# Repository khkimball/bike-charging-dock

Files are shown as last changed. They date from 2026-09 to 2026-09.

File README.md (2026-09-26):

# Bike charging dock

A 3D-printed desk dock for cycling electronics. A multi-port USB charger is
hidden inside, cables run up through the tray to each device, and a hinged lid
closes over them. The shell tapers at 15 degrees on every side and prints in
two colours, a dark foot band and a light body.

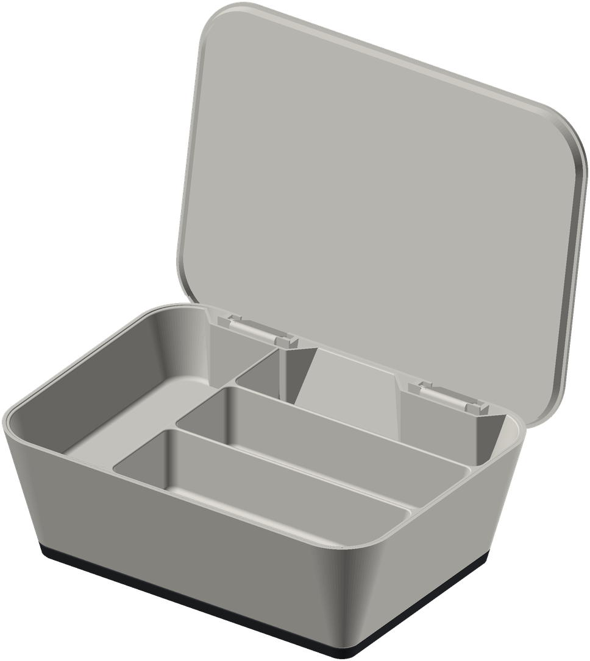
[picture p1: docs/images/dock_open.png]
The dock, open


| Closed | Tray from above | Base from behind |
|---|---|---|
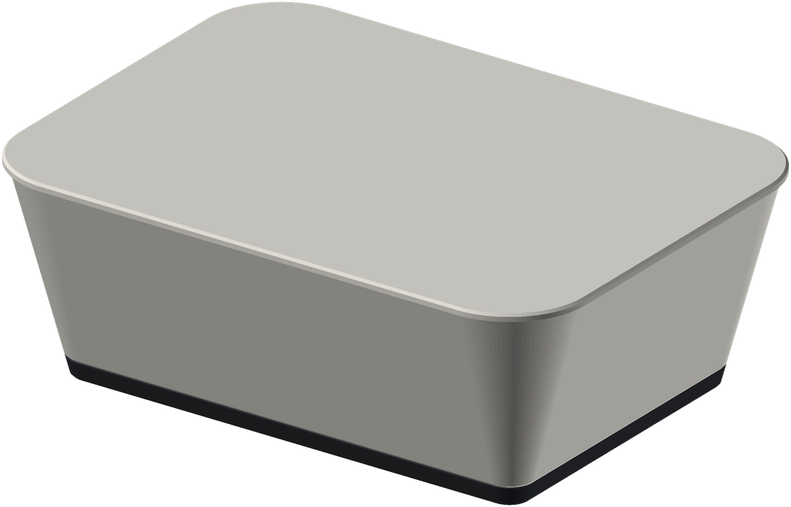
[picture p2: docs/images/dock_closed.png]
Closed
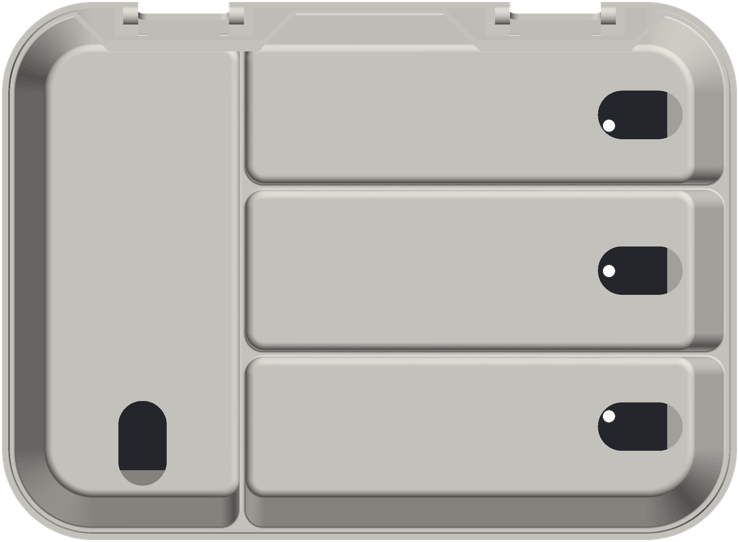
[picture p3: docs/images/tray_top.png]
Tray
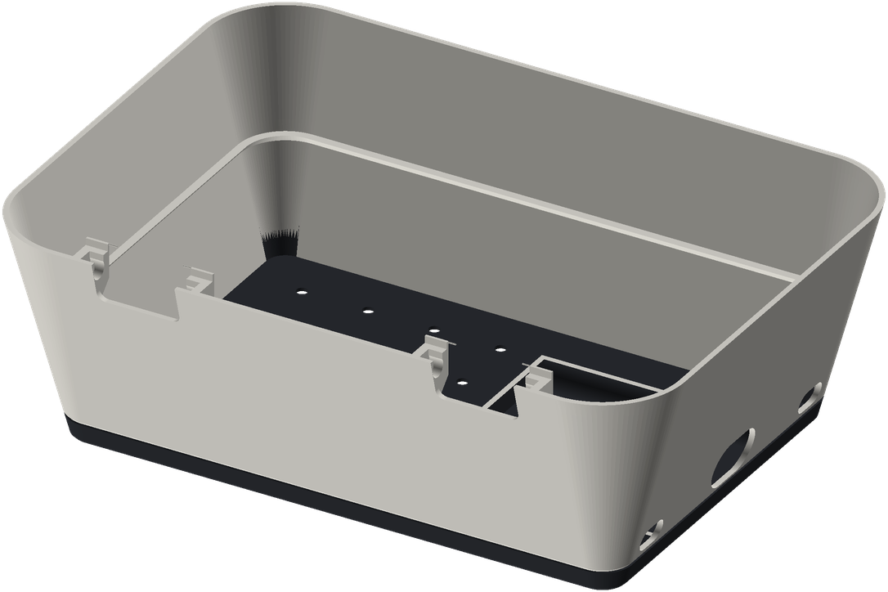
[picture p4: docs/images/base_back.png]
Base
|  |  |  |

- About 250 x 184 x 88 mm closed. The largest part, the lid, is 249.5 x 184.3 mm, so it needs a bed at least 250 mm across.
- Bays are sized for a Wahoo Elemnt Roam 3, a Bontrager Ion headlight and a Wahoo Trackr radar, plus one open bay.
- The charger is an Anker A2154 six-port desktop charger. It stands in a fence in the base, and its mains cord comes in through a port in the end wall.
- Two escape ports beside the charger let a cable out to charge something outside the dock.
- The lid uses a concealed leaf hinge with no hardware. Its printed pins snap into the base, and the lid opens to about 100 degrees and stops there.
- All of it is fully parametric [build123d](https://github.com/gumyr/build123d) code. The tests check the fit, the swing of the lid and printability (no overhang past 45 degrees).

The shape is inspired by the Trek CHRGtime charging station. This project is
not affiliated with or endorsed by Trek.

## What you need

- **Charger:** [Anker Desktop Charger, 112W Max, 6 ports](https://www.amazon.com/dp/B0CM6WDH6S), model A2154 (3 USB-C and 3 USB-A, 77 x 82 x 33 mm). The base's fence and ports are sized for it; check the model number on the label if you buy it elsewhere. Any other charger needs its size entered in `src/dock/measurements.py` (see [Adapt it](#adapt-it)).
- **Cables:** one USB charging cable per device (the charger ships without USB cables).

## Print it

Ready-made STL, STEP and an Orca Slicer project are on the
[releases page](../../releases). The design was printed and tested on a
Snapmaker U1 in PETG; PLA works as well.

| Part | Orientation | Supports |
|---|---|---|
| hinge_test_base, hinge_test_lid | as exported | none (pins: only if they droop) |
| fit_test_plate, fit_test_peg | as exported | none |
| tray | plate down | none |
| base | open top up | **off**, or auto supports will fill the ports |
| lid | top face down | under the leaf pins only if needed |

Settings: 0.4 mm nozzle, 0.2 mm layers, 3 walls, 15 % infill.

- **Print the two test pieces first.** The hinge test is one hinge station cut from the real base and lid. It shows whether the pins snap in and turn freely on your printer before you commit to the big parts. The fit test (a plate of graded holes and a peg) checks the general clearance.
- **Two-tone base:** start in the dark filament and change to the light one at the first layer above 8.0 mm (8.2 mm at 0.2 mm layers). The groove round the foot hides the seam, and the charger fence prints fully dark. With a single-change toolchanger, turn the prime tower off.
- **Fit the lid:** set it on the rim with the leaves over their notches and press the back edge down until the pins snap in. Lift the back edge straight up to take it off.

There is more detail in [docs/printing.md](docs/printing.md).

## Adapt it

Everything is driven by a few files:

- `src/dock/measurements.py` holds your devices, charger and plugs. Measure them with calipers as described in [docs/measuring.md](docs/measuring.md).
- `src/dock/layout.py` sets where the bays go.
- `src/dock/params.py` holds the design rules: wall thickness, clearances, draft angle, colour band.
- `src/dock/hinge.py` sets the hinge fit (`SNAP`, `BORE_CLR`). Tune it with the hinge test.

Then rebuild:

    uv venv --python 3.12 && uv pip install -e ".[dev]"
    uv run pytest                              # fit, swing and printability checks
    uv run python scripts/export_all.py        # out/*.stl and *.step
    uv run python scripts/orca_project.py      # out/orca/dock_plates.3mf, one part per plate
    uv run python scripts/render.py            # docs/images/*.png
    uv run python -m ocp_vscode                # optional viewer at http://localhost:3939

build123d needs Python 3.12. The design history is in
[docs/superpowers/](docs/superpowers/): the specs and plans for each version.

## Parts

- **tray**: a flat plate with four device bays and fixed, filleted dividers. Each bay has an oval cable cutout at its outer end.
- **base**: the tapered, two-tone lower shell. It hides the charger and the cable slack, and carries the tray on a ledge.
- **lid**: a tapered cap whose hinge leaves hang into notches in the base's back wall.
- **test prints**: the fit test (a plate and a peg) and the hinge test.

## License

- Models and images: [CC BY 4.0](LICENSE-models.md).
- Code: [MIT](LICENSE).

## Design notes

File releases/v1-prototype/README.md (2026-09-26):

# v1 prototype — 2026-09-23

Snapshot of the printable files at git tag `v1-prototype` (commit b3ad828).
Printed in PLA on the Snapmaker U1: tray, two dividers, base (supports on the
cord port ceiling only, brim), lid. Charger: Anker A2154 (nominal dimensions;
port pitch, inlet height and cord end still unmeasured at this point).

Regenerate from source with `uv run python scripts/export_all.py`; these
copies are kept so the prototype can be reprinted exactly as it was.

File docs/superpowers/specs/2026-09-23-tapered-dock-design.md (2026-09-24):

# Charging Dock — Tapered Dock Design Spec (physical v2)

Date: 2026-09-23
Status: implemented on branch tapered-dock (plan docs/superpowers/plans/2026-09-24-tapered-dock.md)
Supersedes: the exterior, lid, divider and base-wall parts of
2026-09-20-tray-dock-design.md. The bay layout, devices, charger and cable
routing carry over unless changed here.
Reference: the printed and accepted v1 prototype is tagged `v1-prototype`
(STLs in releases/v1-prototype/).

## Goals

1. **Print efficiency**: at least 25 % less print time *and* filament than
   the v1 set, measured the same way (see Verification).
2. **Match the Trek CHRGtime exterior**: one continuous trapezoid from the
   lid top to the foot. The reference's walls lean about 15° off vertical,
   measured from the manual's to-scale front view (p. 3) and close-up (p. 7).

v1 fit was fine in use, and the Anker A2154 fits the v1 fence as modelled, so
clearances, bay sizes and the charger numbers carry over (the charger values
stay marked NOMINAL until measured).

## Exterior

- **Taper**: a single 15° draft (TAPER_DEG) on every outer face of the base
  and lid. It is a true draft: at depth d below the rim the outline is the rim
  outline offset inward by d·tan 15°, and the corner radius shrinks by the
  same amount.
- **Corners**: R30 at the base rim (CORNER_R), shrinking to about R8 at the
  foot. The lid's corners continue the same surface upward (radius grows
  with height).
- **Size (derived, not frozen)**: rim ≈ 243 × 178, foot ≈ 200 × 135, base
  height ≈ 79.7 (FLOOR + charger + CABLE_ROOM + TRAY_SINK + tray height).
  Everything grows from the tray; nothing is hard-coded.
- **Two-tone base**: dark foot band, light body. The colour line is at
  BAND_H = 8 mm; both kinds of wall port have their sill clamped to sit at
  least 0.5 mm above the groove's top flank (`BAND_H + GROOVE_UP + 0.5`,
  taking whatever is higher against the port's own geometry), so both sit
  entirely in the light body. A reveal groove 1.2 mm tall × 0.6 mm deep is
  centred on the colour line, with asymmetric flanks -- 0.3 mm below, 0.9 mm
  above -- rather than a symmetric 45° V, which would overhang about 52°
  once drafted by TAPER_DEG. The tool change can be set at any layer inside
  the groove, so it works at both 0.20 and 0.28 mm layers. One tool change
  per base; no painted colour.
- **Lid**: LID_H = 8 mm tall with a 1.2 mm top plate (LID_PLATE) and 1.6 mm
  walls (THIN_WALL). The lower 5 mm continues the 15° slope from the base
  rim; the top 3 mm is a flared lip standing 2 mm proud of the slope. The lip
  is the finger grip for opening and echoes the reference's flared lid edge.
  It sits flush on the base rim with no skirt; the hinge locates it. It
  prints top-face-down: its walls lean inward as they rise, so there is no
  overhang. The bed-face edge gets the usual 1 mm chamfer.
- **Removed**: the v1 plinth (the full taper replaces it), the lid skirt,
  the rim rebate and the rim finger notches.
- **Bed limit**: the lid is the largest part (≈ 249.5 × 192 with the lip and hinge hooks). If
  a derived size exceeds BED_X/BED_Y (250) the lip width shrinks first;
  the U1's physical bed is 270.

## Tray

One print, plate down, bays up, no supports.

- **Shell**: its outer walls lean at 15°, parallel to the base wall, and are
  THIN_WALL (1.6) thick; they are hidden inside the base. Plate TRAY_PLATE
  = 1.2 (was 3.0). Its rim is flush with the base rim.
- **Bays**: the same four bays and devices as v1 (ROAM on the left, long
  axis along Y; Ion Pro RT, TRACKR and spare stacked in the right column).
  Bay floors are sized to device + CLR_BAY_OUTER (3.0) at the sloped outer
  walls, which opens to about 13 mm at the top for cables, and device +
  CLR_BAY (8.0) at the vertical internal walls, as in v1. BAY_DEPTH stays 38.
- **Cable cutouts**: ovals (stadiums, full round ends) 28 × 16, like every
  cable hole in the dock (revision 2026-09-24), one at each bay's outer end,
  the headlight bay included (revision 2026-09-24: the Ion's underside
  socket needed three along its bay; its replacement charges from the back,
  so the bay stays Ion-sized with one cutout at the end). They sit within
  each bay's floor, clear of the sloped wall.
- **Fixed internal walls**: the centre partition and the two right-column
  dividers are fused to the plate and outer walls, full bay depth, WALL (2.0)
  thick. There are no rail slots and no RAIL_WALL thickening.
- **Rounding**:
  - R6 on every vertical inside corner, where internal walls meet each other
    or an outer wall.
  - R3 where every wall meets the bay floor.
  - R0.8 on the top edge of every internal wall, not a full round: a full
    round of a WALL-thick (2.0 mm) top would leave no flat face to fillet
    from.

  All of these face up or sideways, so the chamfer-on-downward-edges rule
  does not apply.
- **Lift-out**: by the walls; no finger slot (removed in the 2026-09-24
  revision -- the tray pulls out easily by its walls).

## Base

Prints open-top-up with no supports (the hinge socket blocks sit on 45° chins).

- **Shell**: a single WALL (2.0) sloped wall and a FLOOR (1.2) floor. This
  replaces v1's 2·WALL lower walls, which existed only to carry the rebate
  ledge.
- **Tray ledge**: a continuous ring on the inner wall at the tray's floor
  depth that the tray rests on. It stands 3.0 mm proud of the wall
  (LEDGE_W) and is chamfered underneath, so it prints unsupported. The tray
  rim sits TRAY_SINK = 0.3 below the base rim, so the lid lands on the base. The tray's outer wall
  runs CLR_FIT + 0.3 clear of the base wall, so the ledge sets the tray's
  height, not a taper wedge.
- **Charger**: the v1 U fence, backed onto the −X end wall. That wall leans
  away above the floor, so POCKET_BACK_SLACK (2) is measured at floor level.
  CABLE_ROOM stays 6. Two changes from v1:
  - **Fillets along the charger's sides** (revision 2026-09-24): the
    A2154's long bottom edges are rounded, so the pocket floor meets its two
    side walls in a concave fillet of `Charger.edge_r` + CLR_FIT (NOMINAL
    until measured; see docs/measuring.md), capped below the fence top. No
    fillet on the front wall; all vertical corners square.
  - **Fused to the end wall** (revision 2026-09-24): the side arms run on
    into the leaning −X wall and are trimmed to the base's outside, so they
    join it along the angle at every height.
  - **Height = colour line** (revision 2026-09-24): FENCE_H = BAND_H − FLOOR,
    so the fence top is at 8.0 mm and the whole fence prints dark; the
    filament change goes at the first layer above 8.0.
  - **No fingernail notch**: v1's notch in the +Y fence wall is removed.
    The charger lifts out easily without it.
- **Cord port**: a 26 × 16 oval (stadium, R8 ends) through the −X wall,
  centred on the inlet (revision 2026-09-24; was a rectangle printed on
  supports). A figure-8 (C7) end of CORD_END size passes; its 10 mm flat top
  bridges.
- **Escape ports**: two stadium-shaped holes (nearly oval, up to 14 × 8 with
  full R4 ends) in the −X wall, one each side of the fence. Each is centred
  in Y in the gap between the fence and the side wall, with its sill above
  the colour groove (sill at `BAND_H + GROOVE_UP + 1.5`, i.e. 10.4). This
  replaces the single port above the cord port, which the charger's height
  covered. Each port's length (ESCAPE_L) is derived, capped at 14, so a full
  WALL of material remains to both the fence and the corner arc at that
  height. Their flat heads (ESCAPE_L − ESCAPE_H, up to 6 mm at the cap) are
  short bridges.
- **Cable drop**: the cutouts at the bays' outer ends sit over the leaning
  wall, so a cable falls clear for at least 15 mm below the tray and then
  follows the wall down. v1's rule (clear all the way to the cavity floor)
  cannot hold with a 15° wall.
- **Tie grid and feet**: the tie-down grid (Ø4 on a 24 mm pitch) and the
  four foot recesses stay, re-fitted to the smaller tapered floor.
- **Rim**: plain WALL rim, with no rebate and no notches.
- **Hinge knuckles**: see below.

## Hinge

Revision 2026-09-24b: a concealed leaf hinge after the Trek CHRGtime's
(replacing the knuckle-and-hook hinge). Snap-on, no hardware, on the +Y long
side at two stations about 60 mm in from each end.

- **Notch**: at each station the base's back wall has a notch NOTCH_W
  (30) wide, from the rim down past the leaf with a 2 mm gap below it and
  rounded bottom corners.
- **Leaf**: the lid carries a leaf that hangs into the notch, flush with
  the base's outer wall (same 15° slope), 7 mm thick, reaching LEAF_L
  (8.5) below the pivot, its bottom edge rounded. Closed, the back of the
  dock shows only the leaf in its notch (as the reference).
- **Pins and sockets**: heavy-duty Ø6 pins stand out 5 mm from each leaf
  end along the hinge axis, into sockets in blocks on the inside of the
  base wall beside the notch. The sockets open upward through a neck
  SNAP (0.3) narrower than the pin, so the lid presses straight down onto
  its pins and lifts straight off with a light snap. The axis is 4 mm
  below the rim and 3.5 mm inside the outer face.
- **Back gap**: because the axis is inside the wall line, the lid's back
  edge would dip into the rim as it opens; the lid's back is raised 1.5 mm
  off the rim (BACK_GAP) along the back and round the back corners, as on
  the reference.
- **Stop**: small lips on the socket blocks catch the leaf's ends at about
  101° (OPEN_DEG). They sit only where the leaf's ends go past about 94°
  of opening, clear of both the swing before that and the leaf's path
  straight up when the lid is lifted off; each is tied to its block by a
  riser beside the notch, where the leaf never goes. The riser tops stand
  about 1 mm above the rim, inside the lid.
- **Tray recess**: the tray's back wall steps in around each hinge with
  45° sides (as the reference tray), vertical over the recess, so the
  leaf's swing and the lips have room. The headlight moves 3 mm forward in
  its bay (6 mm clear at the back, 5 mm to the divider) to clear the
  right-hand recess.
- **Printing**: the socket blocks reach in under the lips' risers and sit
  on 45° chins running into the wall, so the base prints without supports
  (revision: the user first chose flat undersides on supports, then asked
  for the chins after seeing the supports in the slicer). Only each lip's
  3 mm ledge into the notch overhangs. The lid's leaf pins are short
  horizontal stubs as it prints top-down.
- **Hinge coupon**: one station cut from the real base and lid, to tune
  BORE_CLR and SNAP and to try the stop before the long prints.

## Removed parts and code

- The `divider` part and `divider.py`, with its tests and its export entry.
- Rail slots, RAIL_WALL and CLR_RAIL. CLR_RAIL stays only if the coupon
  still uses it.
- The plinth, rebate, rim notch, fence fingernail notch and
  single-escape-port geometry, with their tests.

## Print efficiency and verification

- **Baseline** (v1, PETG, U1 0.20 Standard, 3 walls, 15 % infill, base with
  supports):

  | Part | Time | Grams |
  |---|---|---|
  | Base | 5 h 55 m | 266 |
  | Tray | 4 h 22 m | 186 |
  | Lid | 2 h 15 m | 105 |
  | Divider × 2 | 1 h 28 m | 31 |
  | **Total** | **14 h 00 m** | **588** |

- **Target**: the v2 set at 0.20 is at least 25 % below the baseline in both
  time and grams.
- **Measured during planning** (scratch build, slice_report.py, 0.20, PETG;
  v1 through the same script: 14 h 00 m / 582 g):

  | Thicknesses | Time | Grams |
  |---|---|---|
  | 2.0 plates, 2.4 walls (first draft) | 12 h 14 m (−13 %) | 508 (−13 %) |
  | 1.2 plates, 2.4 walls | 10 h 48 m (−23 %) | 450 (−23 %) |
  | **1.2 plates, 2.0 walls (chosen)** | **9 h 53 m (−29 %)** | **412 (−29 %)** |

  The solid plates and walls dominate what the slicer lays down, so the
  chosen set is WALL 2.0, FLOOR / TRAY_PLATE / LID_PLATE 1.2; THIN_WALL
  stays 1.6. The 0.28 mm draft layer for the base and lid is reported
  alongside and recommended in docs/printing.md if it slices cleanly.
- **scripts/slice_report.py**: a new, committed script that slices every
  exported part headlessly with the Snapmaker Orca Flatpak and prints a
  part | time | grams table next to the v1 baseline. Known quirks it must
  handle:
  - It flattens the vendor U1, process and Generic PETG profiles' `inherits`
    chains at run time and keeps `"from": "system"`.
  - It drops the `wipe_tower_filament` key, which segfaults the CLI.
  - It passes `--export-3mf` a bare filename.
  - It reads the estimates from the gcode header inside the exported 3mf.
  - It is not part of pytest.
- **Two-tone cost**: the prime/wipe tower is off for the single tool change,
  and docs/printing.md says so. The slice report slices single-colour, so it
  does not count the one tool change (about a minute).
- **Tests** (pytest, all measuring the built solids):
  - **Taper**: the outline sampled at several heights leans 15° ± 0.5°; the
    corner radius is ≈ R30 at the rim and ≈ R8 at the foot.
  - **Walls**: wall thickness ≥ WALL everywhere, including around both
    escape ports and the cord port.
  - **Tray fit**: seated on the ledge, the tray does not intersect the base,
    its rim is flush within 0.5 mm, and every bay floor holds its device
    plus the specified clearance.
  - **Lid**:
    - it lies on the rim (front and sides; the back is raised BACK_GAP);
    - swept from 0° to just short of OPEN_DEG it intersects neither the
      base nor the seated tray;
    - just past OPEN_DEG the leaf meets the stop lips;
    - lifted straight up while closed, the neck snaps over the pins and
      the lid comes off.
  - **Printability**: no downward face past 45°, with these allowlisted:
    - base: downward faces of 20 mm or less (the ports' flat heads, foot
      recesses, the hinge lips' 3 mm ledges); no supports;
    - lid: the leaf pins' undersides;
    - tray: none.
  - **Parts**: every exported part is a single valid solid with its bed face
    at Z = 0 and fits BED_X × BED_Y.
  - **Colour line**: the groove is at BAND_H, and both kinds of port are
    wholly above it.

## Docs

- docs/printing.md:
  - part table: the divider row goes and the hinge coupon row is added
  - two-tone base: the tool-change layer, and the prime tower off
  - the 0.28 draft profile
  - hinge assembly: snap the lid on at full open
- docs/measuring.md: how to measure the charger's corner radius
  (`Charger.corner_r`).
- CLAUDE.md: note scripts/slice_report.py and the efficiency target.

## Out of scope

Lid latch or magnets, lettering, stickers, LED window, remeasuring the
devices (still NOMINAL, and v1 fit was fine). The charger's corner radius is
the one new measurement.

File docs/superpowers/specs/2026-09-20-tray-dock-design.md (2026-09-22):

# Charging Dock v2 — Tray Design Spec

Date: 2026-09-20
Status: approved in chat (supersedes the cradle deck of the 2026-09-19 spec)

## Why v2

The user showed the Trek CHRGtime reference: devices lie face-up in flat
rectangular bays, each bay has a small rectangular cable cutout at its outer
end that the plug comes up through, dividers are removable, the charger lives
underneath, the box has rounded vertical corners and a shallow lift-off style
cover. v1 stood devices upright in shaped cradles; that is replaced.

## Parts (three printed pieces, plus dividers)

1. **Base** — rounded-corner open box hiding the Anker PowerPort 6 and the
   cable slack. Top rebate receives the tray so the bay walls sit flush with
   the base rim. Charger fence, cord port (a closed 20 × 16 mm hole in the −X end wall below the ledge; the C7 end threads in from outside),
   escape port (rear wall), LED window (+X end wall), foot recesses. The floor
   area beside the charger (the port side) carries a grid of 4 mm holes on a
   12 mm pitch for tying cable slack down, as in the reference teardown.
2. **Tray** — a plate with 2.4 mm walls forming four bays, 32 mm deep (BAY_DEPTH, ≥ tallest device + 1):
   - Left bay: Wahoo ROAM 3 lying face-up, long axis along Y, cable cutout at
     the front (−Y) end.
   - Right column, three bays stacked in Y, long axis along X, cable cutouts at
     the +X end: Bontrager Ion Pro RT (top, +Y), Wahoo TRACKR (middle), spare
     (bottom, −Y).
   - The Ion Pro RT charges through a socket on its underside, so its bay has
     three cutouts evenly spaced along the bay instead of one at the end
     (UNDERSIDE_PORT_CUTOUTS in tray.py); the cable drops straight down.
   - The two separators in the right column are removable dividers riding in
     rail slots on the partition wall and the +X outer wall, so bays can be
     merged. The left/right partition and the outer walls are fixed.
   - Each cable cutout is a rectangular through-hole in the plate, 22 × 12 mm,
     so the plug lies flat beside the device with the cable dropping into the
     base cavity.
   - Bay clearance: 3 mm per side around each device (bays, not pockets).
3. **Lid** — a shallow cap: 2.4 mm top plate with an 8 mm skirt that drops
   over the outside of the base top with CLR_FIT. Same rounded corners.
   Prints top-face-down. No hinge.
4. **Divider** — existing rectangular-rail slab, height = bay depth, width =
   bay width − CLR_RAIL.

## Geometry rules

- Vertical outer corners filleted R8 on base and lid; the tray's outer corners
  follow (R8 − WALL − CLR_FIT). Bay inner corners stay square.
- Wall 2.4, floor 1.6, tray plate 3.0. Chamfers on downward edges, no
  overhang past 45°, bridges ≤ 20 mm allowed.
- Clearances: CLR_FIT 0.15 (coupon, PLA), CLR_RAIL 0.20, CLR_BAY 3.0.
- Bed limit raised to 250 × 250 (U1 is 270 cube); target footprint about
  205 × 140 mm, base height about 75 mm.
- Base height = FLOOR + charger height + CABLE_ROOM 6 + tray height (plate +
  bay depth).
- Charger (Anker A2154 since 2026-09-21; 3 USB-C + 3 USB-A, no LED): its back
  sits against the −X end wall (2 mm slack) with the fence a U of two sides and
  a front; the AC cord plugs in from outside through the cord port straight
  into the inlet; ports face the cavity centre with ≥ 40 mm plug room. A row of
  six cable loops (a comb, one window per port) stands 24 mm in front of the
  fence; cables run under it toward the centre, then up through the cutouts.
  The escape port sits directly above the cord port in the same wall. Cavity must clear the
  fence by ≥ 2 mm per side in Y; the tray's Y is driven by the bays, and the
  base grows only if the fence needs it.
- Measurements: ROAM 96 × 53 × 24 (published), ION 102.5 × 30.2 × 34.7
  (published; lying flat it is 34.7 wide × 30.2 tall), TRACKR 89.9 × 37.1 ×
  29.1 (published, conflicting), CHARGER nominal 96 × 65 × 26 until measured.
  The ION measurement becomes a Slab (length, width, thickness).

## Removed from v1

cradles.py and deck.py and their tests; the Cylinder measurement type; the
port_face/port_height fields (devices lie flat; the plug is horizontal in the
bay).

## Out of scope

Hinge, felt lining, lid latch, lettering, numbered stickers.

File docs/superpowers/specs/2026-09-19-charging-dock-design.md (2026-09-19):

# Cycling Electronics Charging Dock — Design Spec

Date: 2026-09-19
Status: approved in brainstorming, pending spec review

## Goal

A desktop charging dock, in the spirit of the Trek CHRGtime, that hides a
multi-port USB charger and its cables and presents tidy cradles for three
specific devices plus one spare bay. Printed in PETG on a Snapmaker U1.

## Devices

| Device | Port | Charging posture |
|---|---|---|
| Wahoo Elemnt Roam 3 | USB-C (rear) | Face-up on a sloped shelf, cable rises through a slot behind it |
| Bontrager Ion Pro RT | Micro-USB (bottom) | Standing upright in a ring; cable rises from below into the port |
| Wahoo Trackr tail light | USB-C | Upright in a small pocket, cable rises from below |
| Spare bay | any | Open bay with a removable divider; cable through a floor slot |

All device pocket dimensions come from caliper measurements the user takes
(measurement list is a deliverable of the plan). Nothing is guessed from
marketing photos.

## Power

Anker PowerPort 6 (model A2123): 60 W desktop charger, six USB-A ports on
one face, detachable AC cord (C7 figure-8 inlet on the opposite face), LED
next to the ports. Approximate body 96 x 65 x 26 mm; the user measures the
actual unit (body, port-face offsets, inlet position, LED position) before
the base is printed, and the cavity is fully parametric.

Cables are all USB-A on the charger end: 2x USB-A to USB-C (Roam 3, Trackr)
and 1x USB-A to Micro-USB (Ion Pro RT), plus spares for the open bay. The
port face points toward the cable channels; the AC cord exits the rear
through a notch; the LED is visible through a small window or light pipe
hole in the base side.

## Geometry

Two printed pieces:

1. **Base tray** — holds the charger in a friction-fit cavity with a
   fingernail relief for removal, AC cord notch at the rear, rear "escape
   port" slot (a spare cable can leave the box to charge something on top),
   four rubber-foot recesses underneath. Open top.
2. **Deck** — sits on the base with a 0.2 mm lip fit and locates on
   corner pegs. Contains the three cradles and the spare bay. Underside has
   snap-in cable channels from each charger port to each cradle's floor
   slot. Each floor slot is sized for the cable's connector overmold plus
   0.3 mm so the plug sits captive with its tip proud of the floor.

Dividers: a single 2 mm slab with dovetail rails that drop into slots along
the spare bay walls.

Design rules:
- Wall thickness 2.4 mm (3 perimeters at 0.4 mm), floors 1.6 mm.
- Chamfers instead of fillets on downward-facing edges; no overhang past
  45 degrees without a designed-in support feature.
- Clearances: 0.3 mm device pockets, 0.2 mm deck-to-base, 0.25 mm divider
  rails. All tunable from one params block, calibrated by a fit coupon.
- Overall footprint target under 250 x 120 mm so it fits the U1 bed with
  margin; enforced by a test.

## Toolchain

- Python 3 venv in this repo: `build123d`, `ocp-vscode` (live browser
  viewer), `pytest`.
- `src/dock/params.py` — every dimension, with docstrings.
- `src/dock/base.py`, `src/dock/deck.py`, `src/dock/divider.py`,
  `src/dock/coupon.py` — one build function each returning a build123d
  Part.
- `src/dock/export.py` — writes STL, 3MF, STEP into `out/` (gitignored).
- `tests/` — bounding box, wall thickness sanity, pocket-to-device
  clearance, deck/base fit, bed-size limit.
- Slicer: OrcaSlicer (Flatpak) with the Snapmaker U1 PETG profile; the
  user slices and prints.

Onshape is not used. STEP export exists in case it is wanted later.

## Iteration sequence

1. Toolchain up, calibration coupon printed, clearances set from results.
2. User measures devices and charger; params filled in.
3. Cradle-only test prints (each cradle as a small standalone part).
4. Full deck, then base. Fit check, tune, reprint.

## Out of scope for v1

Lids, lighting, numbered stickers, Gridfinity compatibility, multi-material.

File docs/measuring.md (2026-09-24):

# What to measure (digital calipers, mm, one decimal)

Enter each value in `src/dock/measurements.py`, then run `uv run pytest`.

Each device is a `Slab(length, width, thickness)`: it lies face-up flat in
its bay, `length` along the bay, `width` across it, `thickness` = height
above the bay floor.

## Wahoo Roam 3 (`ROAM`)
- length: top to bottom edge, at the widest, along the bay
- width: side to side at the widest, across the bay
- thickness: face to back, including the rear mount tabs -- how tall it
  stands above the bay floor
- Published values now in the file: `Slab(96.0, 53.0, 24.0)`.

## Bontrager Ion Pro RT (`ION`)
Lies flat on its side, not standing on its tail.
- length: lens face to tail, along the bay
- width: body diameter across the bay (34.7 mm)
- thickness: body diameter above the bay floor (30.2 mm) -- the Ion's body is
  not perfectly round, so width and thickness may differ slightly; use the
  cross-section as it actually rests
- Published values now in the file: `Slab(102.5, 34.7, 30.2)`.

## Wahoo Trackr (`TRACKR`)
- length, width, thickness of the body without the mount clip, lying flat
- Published values now in the file: `Slab(89.9, 37.1, 29.1)`.

## Anker A2154 112 W six-port charger (`CHARGER`)
Published: 77 x 82 x 33 mm, 302 g; three USB-C and three USB-A in one row on
the front face; AC inlet centred on the back face; no status LED.  Lay the
charger flat, ports toward you.
- port_face_width: the long horizontal dimension -- the face carrying the
  six ports
- port_to_inlet: the other horizontal dimension, port face to inlet face.
  Measure the back face to the port face *including anything proud of the
  back* -- an inlet shroud, a moulded label boss, a raised badge.  The base
  backs the charger onto the cavity's end wall and leaves
  `base.POCKET_BACK_SLACK` (2 mm) of free X behind it for exactly that; if
  what stands proud of the back is more than that, raise the slack rather
  than fudging this measurement.
- height: the remaining (vertical) dimension with the charger lying flat
- port_face_margin: charger edge to centre of the first port, measured along
  the port face
- port_pitch: centre to centre between adjacent ports.  Measure port 1 to
  port 6 and divide by five rather than measuring one gap -- five gaps share
  the error out.  Anker does not publish it; the file has a NOMINAL 12.5 with
  the row centred on the face, which is where `port_face_margin` comes from
  too.  Nothing in the base depends on it now that the charger's own cable
  block replaces the printed loops; it only positions the plug-clearance test.
- inlet_center_z: bottom of charger to centre of the AC inlet.  NOMINAL is
  half the body height.  The base's cord port has to span this, and the port
  narrows into a 45 degree peak above its rectangular part, so an inlet
  higher than expected is a real failure -- `test_base.py` measures it.
- led_offset_from_ports: `None` when the charger has no status LED.  The
  A2154 has none, and the base (this tapered v2 design) has no LED window and
  never reads this field regardless -- it is kept for a future charger that
  has one.  If yours does have an LED, measure from port 1's centre to the
  LED centre along the port face, *away* from the other ports: the LED sits
  at the end of the row, outboard of port 1, not between the ports.
- edge_r: the radius of the rounded bottom edges along the charger's two
  sides (the faces either side of the port face), seen end-on.  Stand the
  charger on the bench, hold a square (or a card) flat against the bench and
  up against one side, and measure how far up the side, or in under the
  bottom, the curve starts -- that distance is the radius.  The pocket's
  floor meets its two side walls in a fillet of `edge_r + CLR_FIT` that
  follows those edges.  NOMINAL 6.0 until measured.
- Check what the AC inlet actually is while you have the charger in hand.
  `CORD_END` below is still sized for an IEC C7 "figure of 8"; a C13 or C5
  inlet is a different shape and the cord port must be resized from it.

## Mains cord end (`CORD_END`, a `params.Plug`)
The moulded end of the charger's mains cord -- an IEC C7 "figure of 8"
connector.  The base's cord port is sized from it, so measure the moulded
body, not the cable:
- width: across the two lobes, at the widest point of the moulding
- height: across the flats, the short way through the moulding
- length: along the cord axis, from the face that meets the inlet to where
  the moulding tapers back into the cable
A C7 end is nominally 24 x 14 mm; check yours, some are fatter.

## Cables (`params.py` Plug entries)
- For each cable: overmold width, height and length at the device end and
  the USB-A end. Update `USB_A_PLUG`, `USB_C_PLUG`, `MICRO_PLUG` with the
  largest of each.
- Nothing is cut to these: every bay gets the same cable cutout
  (`tray.CUTOUT`, 28 x 16 through the plate). They are the check that the
  cutout is big enough -- if a remeasured overmold outgrows it, widen the
  cutout.

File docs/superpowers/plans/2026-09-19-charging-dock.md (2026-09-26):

# Charging Dock Implementation Plan

> **For agentic workers:** REQUIRED SUB-SKILL: Use superpowers:subagent-driven-development (recommended) or superpowers:executing-plans to implement this plan task-by-task. Steps use checkbox (`- [ ]`) syntax for tracking.

**Goal:** A two-piece PETG charging dock (base tray + deck) hiding an Anker PowerPort 6 and holding a Wahoo Roam 3, a Bontrager Ion Pro RT and a Wahoo Trackr, printed on a Snapmaker U1.

**Architecture:** Pure-Python parametric CAD with build123d's algebra API. One module per printed part, each exposing a `build_*()` function that returns a `build123d.Part`. All dimensions live in `params.py` (design rules) and `measurements.py` (values the user measures with calipers). Tests assert geometry facts (bounding box, clearances, bed fit, validity). `export.py` writes STL/3MF/STEP into `out/`.

**Tech Stack:** Python 3.12 via `uv` (build123d has no 3.14 wheels yet), build123d, ocp_vscode (browser viewer), pytest. Slicing in the already-installed Snapmaker Orca Flatpak (`io.github.Snapmaker.Snapmaker_Orca`).

**Spec:** `docs/superpowers/specs/2026-09-19-charging-dock-design.md`

## Global Constraints

- Wall thickness 2.4 mm, floors 1.6 mm.
- Clearances: 0.3 mm device pockets, 0.2 mm deck-to-base, 0.25 mm divider rails. All in `params.py`, tunable after the coupon print.
- Overall footprint under 250 x 120 mm (U1 bed with margin), enforced by a test.
- Chamfers, not fillets, on downward-facing edges. No overhang past 45 degrees.
- Charger: Anker PowerPort 6 (A2123), six USB-A on one face, C7 inlet on the opposite face. Nominal 96 x 65 x 26 mm until measured.
- Units: millimetres everywhere. Z is up. Parts are built with their print-bed face at Z=0.
- `out/` is gitignored; never commit exports.
- Every commit message ends with `Co-Authored-By: Claude Fable 5.1 <noreply@anthropic.com>`.

## File Structure

```
pyproject.toml            project metadata, deps, pytest config
.python-version           "3.12"
src/dock/__init__.py      empty
src/dock/params.py        design rules: walls, clearances, bed limits, cable connector sizes
src/dock/measurements.py  caliper-measured device and charger dimensions (user edits)
src/dock/export.py        write_all(part, name) -> STL/3MF/STEP in out/
src/dock/coupon.py        build_coupon(): clearance calibration test piece
src/dock/cradles.py       build_roam_cradle(), build_ion_cradle(), build_trackr_cradle()
src/dock/divider.py       build_divider()
src/dock/deck.py          build_deck(): cradles + spare bay + cable slots + lip
src/dock/base.py          build_base(): charger cavity, cord notch, escape port, LED window, feet
src/dock/view.py          show any part in ocp_vscode viewer
scripts/export_all.py     exports every part
tests/conftest.py         shared fixtures
tests/test_params.py
tests/test_coupon.py
tests/test_cradles.py
tests/test_divider.py
tests/test_deck.py
tests/test_base.py
tests/test_assembly.py
docs/measuring.md         what the user measures and where it goes
README.md
```

---

### Task 1: Project scaffold, params, export helper

**Files:**
- Create: `pyproject.toml`, `.python-version`, `src/dock/__init__.py`, `src/dock/params.py`, `src/dock/export.py`, `src/dock/view.py`, `tests/conftest.py`, `tests/test_params.py`, `README.md`

**Interfaces:**
- Produces: `params.WALL=2.4`, `params.FLOOR=1.6`, `params.CLR_DEVICE=0.3`, `params.CLR_FIT=0.2`, `params.CLR_RAIL=0.25`, `params.BED_X=250`, `params.BED_Y=120`, `params.CHAMFER=1.0`, `params.USB_A_PLUG` (dataclass w/ `width, height, length`), `params.USB_C_PLUG`, `params.MICRO_PLUG`; `export.write_all(part: Part, name: str, out_dir: Path = Path("out")) -> list[Path]`; `view.show_part(part)`.

- [ ] **Step 1: Create the environment**

```bash
cd bike-charging-dock
echo "3.12" > .python-version
uv venv --python 3.12
```

- [ ] **Step 2: Write pyproject.toml**

```toml
[project]
name = "dock"
version = "0.1.0"
description = "Parametric 3D-printed charging dock for cycling electronics"
requires-python = ">=3.12,<3.13"
dependencies = ["build123d>=0.9", "ocp_vscode>=2.6"]

[project.optional-dependencies]
dev = ["pytest>=8"]

[build-system]
requires = ["hatchling"]
build-backend = "hatchling.build"

[tool.hatch.build.targets.wheel]
packages = ["src/dock"]

[tool.pytest.ini_options]
testpaths = ["tests"]
```

- [ ] **Step 3: Install**

```bash
uv pip install -e ".[dev]"
```
Expected: build123d imports (`uv run python -c "import build123d"` prints nothing).

- [ ] **Step 4: Write the failing test**

`tests/test_params.py`:
```python
from dock import params

def test_design_rules_match_spec():
    assert params.WALL == 2.4
    assert params.FLOOR == 1.6
    assert params.CLR_DEVICE == 0.3
    assert params.CLR_FIT == 0.2
    assert params.CLR_RAIL == 0.25
    assert (params.BED_X, params.BED_Y) == (250, 120)

def test_plug_sizes_are_positive():
    for plug in (params.USB_A_PLUG, params.USB_C_PLUG, params.MICRO_PLUG):
        assert plug.width > 0 and plug.height > 0 and plug.length > 0
```

- [ ] **Step 5: Run it, expect ImportError**

`uv run pytest tests/test_params.py -v` → FAIL, `ModuleNotFoundError: dock.params`.

- [ ] **Step 6: Write params.py**

```python
"""Design rules. Millimetres. Change here, never inline in a part module."""
from dataclasses import dataclass

WALL = 2.4        # 3 perimeters at 0.4 mm nozzle
FLOOR = 1.6       # 4 layers at 0.4 mm
CHAMFER = 1.0     # downward-facing edge chamfer
CLR_DEVICE = 0.3  # device pocket clearance per side
CLR_FIT = 0.2     # deck lip into base
CLR_RAIL = 0.25   # divider dovetail rails
BED_X = 250       # U1 usable X with margin
BED_Y = 120       # self-imposed footprint limit

@dataclass(frozen=True)
class Plug:
    """Cable connector overmold envelope (the moulded body, not the metal tip)."""
    width: float
    height: float
    length: float   # overmold length along the cable axis

# Typical overmold sizes; refine from the actual cables when measured.
USB_A_PLUG = Plug(width=15.0, height=8.0, length=20.0)
USB_C_PLUG = Plug(width=11.0, height=6.0, length=18.0)
MICRO_PLUG = Plug(width=10.5, height=6.5, length=17.0)
```

`src/dock/__init__.py`: empty file.

- [ ] **Step 7: Run tests, expect pass**

`uv run pytest tests/test_params.py -v` → 2 passed.

- [ ] **Step 8: Write export.py and view.py**

`src/dock/export.py`:
```python
from pathlib import Path
from build123d import Part, Mesher, export_stl, export_step

def write_all(part: Part, name: str, out_dir: Path = Path("out")) -> list[Path]:
    """Write STL, 3MF and STEP for `part`. Returns the paths written."""
    out_dir.mkdir(parents=True, exist_ok=True)
    stl = out_dir / f"{name}.stl"
    threemf = out_dir / f"{name}.3mf"
    step = out_dir / f"{name}.step"
    export_stl(part, str(stl))
    m = Mesher()
    m.add_shape(part)
    m.write(str(threemf))
    export_step(part, str(step))
    return [stl, threemf, step]
```

`src/dock/view.py`:
```python
"""Run `uv run python -m ocp_vscode` in one terminal, then call show_part()."""
from build123d import Part
from ocp_vscode import show

def show_part(part: Part) -> None:
    show(part)
```

- [ ] **Step 9: Test export writes three files**

Append to `tests/test_params.py`:
```python
from pathlib import Path
from build123d import Box
from dock.export import write_all

def test_write_all_creates_three_files(tmp_path: Path):
    paths = write_all(Box(10, 10, 10), "cube", tmp_path)
    assert [p.suffix for p in paths] == [".stl", ".3mf", ".step"]
    assert all(p.stat().st_size > 0 for p in paths)
```
`uv run pytest tests/test_params.py -v` → 3 passed.

- [ ] **Step 10: README and commit**

`README.md`:
```markdown
# Charging dock

Parametric build123d model of a desktop charging dock. See
`docs/superpowers/specs/2026-09-19-charging-dock-design.md`.

    uv venv --python 3.12 && uv pip install -e ".[dev]"
    uv run pytest
    uv run python scripts/export_all.py     # writes out/*.stl|3mf|step
    uv run python -m ocp_vscode             # viewer at http://localhost:3939
```

```bash
git add -A && git commit -m "Scaffold build123d project with params and export

Co-Authored-By: Claude Fable 5.1 <noreply@anthropic.com>"
```

---

### Task 2: Calibration coupon

**Files:**
- Create: `src/dock/coupon.py`, `tests/test_coupon.py`, `scripts/export_all.py`

**Interfaces:**
- Consumes: `export.write_all` only. The coupon deliberately uses fixed sizes: it calibrates params, so it must not depend on them.
- Produces: `coupon.build_coupon() -> Part`, `coupon.CLEARANCES = (0.1, 0.15, 0.2, 0.25, 0.3, 0.4)`; `scripts/export_all.py` with a `PARTS: dict[str, Callable[[], Part]]` registry that later tasks append to.

The coupon is a plate with six 10 mm square holes and a separate 10 mm square peg. Each hole is 10 + 2*c across, labelled by its position (smallest clearance nearest the notch). The user pushes the peg into each hole; the tightest one that slides in by hand gives the fit clearance, the one that drops freely gives the device clearance.

- [ ] **Step 1: Failing test**

`tests/test_coupon.py`:
```python
from build123d import Axis
from dock import coupon

def test_coupon_has_six_holes():
    plate, peg = coupon.build_coupon()
    # a plate with 6 through-holes has 6 inner wires on its top face
    top = plate.faces().sort_by(Axis.Z)[-1]
    assert len(top.inner_wires()) == 6

def test_peg_is_10mm_square():
    _, peg = coupon.build_coupon()
    size = peg.bounding_box().size
    assert abs(size.X - 10) < 1e-6 and abs(size.Y - 10) < 1e-6
```

- [ ] **Step 2: Run, expect failure** — `uv run pytest tests/test_coupon.py -v` → ModuleNotFoundError.

- [ ] **Step 3: Implement**

`src/dock/coupon.py`:
```python
"""Clearance calibration coupon: one plate with 6 graded holes, one peg."""
from build123d import Box, Pos, Part, Align

CLEARANCES = (0.1, 0.15, 0.2, 0.25, 0.3, 0.4)
PEG = 10.0
PITCH = 16.0
THICK = 4.0

def build_coupon() -> tuple[Part, Part]:
    n = len(CLEARANCES)
    plate = Box(PITCH * n + 6, PITCH + 6, THICK, align=(Align.MIN, Align.MIN, Align.MIN))
    for i, c in enumerate(CLEARANCES):
        hole = Box(PEG + 2 * c, PEG + 2 * c, THICK, align=(Align.CENTER, Align.CENTER, Align.MIN))
        plate -= Pos(3 + PITCH * i + PITCH / 2, 3 + PITCH / 2, 0) * hole
    # orientation notch beside the tightest hole
    plate -= Pos(0, 0, 0) * Box(3, 3, THICK, align=(Align.MIN, Align.MIN, Align.MIN))
    peg = Box(PEG, PEG, THICK * 2, align=(Align.CENTER, Align.CENTER, Align.MIN))
    return plate, peg
```

- [ ] **Step 4: Run, expect pass.**

- [ ] **Step 5: Export script**

`scripts/export_all.py`:
```python
"""Export every registered part into out/."""
from typing import Callable
from build123d import Part
from dock.export import write_all
from dock import coupon

def _coupon_plate() -> Part:
    return coupon.build_coupon()[0]

def _coupon_peg() -> Part:
    return coupon.build_coupon()[1]

PARTS: dict[str, Callable[[], Part]] = {
    "coupon_plate": _coupon_plate,
    "coupon_peg": _coupon_peg,
}

if __name__ == "__main__":
    for name, fn in PARTS.items():
        for p in write_all(fn(), name):
            print(p)
```
Run `uv run python scripts/export_all.py`; expect six paths under `out/`.

- [ ] **Step 6: Commit**

```bash
git add -A && git commit -m "Add clearance calibration coupon

Co-Authored-By: Claude Fable 5.1 <noreply@anthropic.com>"
```

- [ ] **Step 7: User action (blocking for later tuning, not for later tasks)**
Print `out/coupon_plate.stl` and `out/coupon_peg.stl` on the U1 in PETG. Report which hole the peg slides into with light finger pressure (→ `CLR_FIT`) and which it falls through (→ `CLR_DEVICE`). Update `params.py` accordingly.

---

### Task 3: Measurements module and measuring guide

**Files:**
- Create: `src/dock/measurements.py`, `docs/measuring.md`, `tests/test_measurements.py`

**Interfaces:**
- Produces: dataclass instances `measurements.ROAM`, `measurements.ION`, `measurements.TRACKR` (fields: `length, width, thickness` for Roam; `diameter, length, port_offset_from_axis` for Ion; `length, width, thickness` for Trackr) and `measurements.CHARGER` (fields: `length, width, height, port_face_margin, inlet_center_z, led_offset_from_ports`). Nominal published values are the defaults; the user overwrites them.

- [ ] **Step 1: Failing test**

`tests/test_measurements.py`:
```python
from dock import measurements as m

def test_all_measurements_positive():
    for obj in (m.ROAM, m.ION, m.TRACKR, m.CHARGER):
        for k, v in vars(obj).items():
            assert v > 0, f"{type(obj).__name__}.{k} must be > 0"

def test_charger_is_powerport6_sized():
    # sanity envelope for an Anker A2123; fails loudly if someone types cm
    assert 80 < m.CHARGER.length < 110
    assert 55 < m.CHARGER.width < 75
    assert 20 < m.CHARGER.height < 32
```

- [ ] **Step 2: Run, expect failure.**

- [ ] **Step 3: Implement**

`src/dock/measurements.py`:
```python
"""Caliper measurements. EDIT THESE after measuring the real objects.
All mm. Defaults are nominal/published values, marked NOMINAL."""
from dataclasses import dataclass

@dataclass(frozen=True)
class Slab:
    """A flat device measured lying face-up."""
    length: float     # longest dimension
    width: float
    thickness: float

@dataclass(frozen=True)
class Cylinder:
    """A round-bodied device standing on its charge-port end."""
    diameter: float
    length: float
    port_offset_from_axis: float  # micro-USB port centre distance from body axis

@dataclass(frozen=True)
class Charger:
    length: float               # port face to inlet face
    width: float
    height: float
    port_face_margin: float     # distance from charger edge to first port centre
    inlet_center_z: float       # C7 inlet centre height above charger bottom
    led_offset_from_ports: float  # LED centre distance from nearest port centre

ROAM = Slab(length=89.8, width=60.7, thickness=16.5)          # NOMINAL Wahoo spec
ION = Cylinder(diameter=32.0, length=100.0, port_offset_from_axis=6.0)  # NOMINAL guess
TRACKR = Slab(length=60.0, width=28.0, thickness=17.0)       # NOMINAL guess
CHARGER = Charger(length=96.0, width=65.0, height=26.0,
                  port_face_margin=10.0, inlet_center_z=13.0,
                  led_offset_from_ports=8.0)                  # NOMINAL A2123
```

- [ ] **Step 4: Run, expect pass.**

- [ ] **Step 5: Measuring guide**

`docs/measuring.md`:
```markdown
# What to measure (digital calipers, mm, one decimal)

Enter each value in `src/dock/measurements.py`, then run `uv run pytest`.

## Wahoo Roam 3 (`ROAM`)
- length: top to bottom edge, at the widest
- width: side to side at the widest
- thickness: face to back, including the rear mount tabs
- Also note: distance from the bottom edge to the USB-C port centre, and
  whether the port is on the back or the bottom edge (write it in a comment).

## Bontrager Ion Pro RT (`ION`)
- diameter: body diameter at the widest point
- length: lens face to tail
- port_offset_from_axis: with the light standing on its tail, distance from
  the body centre to the micro-USB port centre (0 if centred)

## Wahoo Trackr (`TRACKR`)
- length, width, thickness of the body without the mount clip
- Note where the USB-C port sits (end or side) in a comment.

## Anker PowerPort 6 (`CHARGER`)
- length: port face to C7 inlet face
- width, height (height = the dimension when the ports are on a vertical face)
- port_face_margin: charger edge to centre of the first USB port
- inlet_center_z: bottom of charger to centre of the C7 inlet
- led_offset_from_ports: nearest port centre to LED centre

## Cables (`params.py` Plug entries)
- For each cable: overmold width, height and length at the device end and
  the USB-A end. Update `USB_A_PLUG`, `USB_C_PLUG`, `MICRO_PLUG` with the
  largest of each.
```

- [ ] **Step 6: Commit**

```bash
git add -A && git commit -m "Add measurement inputs and measuring guide

Co-Authored-By: Claude Fable 5.1 <noreply@anthropic.com>"
```

- [ ] **Step 7: User action:** measure per `docs/measuring.md`, edit `measurements.py`, commit.

---

### Task 4: Cradles

**Files:**
- Create: `src/dock/cradles.py`, `tests/test_cradles.py`
- Modify: `scripts/export_all.py` (register three cradles)

**Interfaces:**
- Consumes: `params.WALL, FLOOR, CLR_DEVICE, CHAMFER, USB_C_PLUG, MICRO_PLUG`; `measurements.ROAM, ION, TRACKR`.
- Produces: `build_roam_cradle() -> Part`, `build_ion_cradle() -> Part`, `build_trackr_cradle() -> Part`. Every cradle: print face at Z=0, footprint centred on origin, a rectangular through-slot in its floor sized to the device-end plug + `CLR_DEVICE`, so a plug pushed up from below sits captive with the metal tip proud of the floor. Also `cradle_footprint(part) -> tuple[float, float]` returning X/Y size, used by `deck.py`.

Geometry:
- Roam: a shelf tilted 20 degrees toward the user, pocket = device + clearance on three sides, open at the top edge, floor slot behind the bottom edge where the USB-C port is.
- Ion: a ring (ID = diameter + 2*CLR_DEVICE, wall = WALL, height 25 mm) on a floor with the micro slot at `port_offset_from_axis`.
- Trackr: upright pocket, device standing on its port end, pocket depth 60 % of length, USB-C slot in the floor.

- [ ] **Step 1: Failing tests**

`tests/test_cradles.py`:
```python
import pytest
from build123d import Axis
from dock import cradles, params
from dock import measurements as m

@pytest.mark.parametrize("fn", [cradles.build_roam_cradle,
                                cradles.build_ion_cradle,
                                cradles.build_trackr_cradle])
def test_cradle_is_valid_and_sits_on_bed(fn):
    p = fn()
    assert p.is_valid()
    bb = p.bounding_box()
    assert abs(bb.min.Z) < 1e-6

def test_ion_ring_inner_diameter_has_clearance():
    p = cradles.build_ion_cradle()
    # the ring's inner cylindrical face radius
    inner = [f for f in p.faces() if f.geom_type.name == "CYLINDER"]
    radii = sorted(f.radius for f in inner)
    assert abs(radii[0] - (m.ION.diameter / 2 + params.CLR_DEVICE)) < 1e-6

def test_trackr_pocket_wider_than_device():
    p = cradles.build_trackr_cradle()
    top = p.faces().sort_by(Axis.Z)[-1]
    inner = top.inner_wires()
    assert len(inner) == 1
    size = inner[0].bounding_box().size
    assert size.X >= m.TRACKR.width + 2 * params.CLR_DEVICE - 1e-6
    assert size.Y >= m.TRACKR.thickness + 2 * params.CLR_DEVICE - 1e-6

def test_every_cradle_has_a_floor_slot():
    for fn in (cradles.build_roam_cradle, cradles.build_ion_cradle,
               cradles.build_trackr_cradle):
        p = fn()
        bottom = p.faces().sort_by(Axis.Z)[0]
        assert len(bottom.inner_wires()) >= 1, fn.__name__
```

- [ ] **Step 2: Run, expect failure.**

- [ ] **Step 3: Implement**

`src/dock/cradles.py`:
```python
"""Three device cradles. Each is printable standalone for fit testing."""
from build123d import Box, Cylinder, Pos, Rot, Part, Align, Plane, chamfer, Axis
from dock import params as P
from dock import measurements as M

_MIN = (Align.CENTER, Align.CENTER, Align.MIN)

def _slot(plug: P.Plug) -> Part:
    """Through-slot for a plug overmold pushed up from below (Z-thru box)."""
    return Box(plug.width + 2 * P.CLR_DEVICE, plug.height + 2 * P.CLR_DEVICE, 100,
               align=(Align.CENTER, Align.CENTER, Align.CENTER))

def cradle_footprint(part: Part) -> tuple[float, float]:
    s = part.bounding_box().size
    return (s.X, s.Y)

def build_roam_cradle() -> Part:
    c = P.CLR_DEVICE
    pw = M.ROAM.width + 2 * c          # pocket width (X)
    pl = M.ROAM.length * 0.5 + c       # pocket holds the lower half
    pd = M.ROAM.thickness + 2 * c      # pocket depth into the shelf
    ow, ol, oh = pw + 2 * P.WALL, pl + P.WALL, pd + P.FLOOR
    shelf = Box(ow, ol, oh, align=_MIN)
    pocket = Pos(0, P.WALL / 2, P.FLOOR) * Box(pw, pl, pd, align=_MIN)  # open on +Y
    shelf -= pocket
    # slot behind the bottom edge, where the USB-C port is
    shelf -= Pos(0, -pl / 2 + P.USB_C_PLUG.height / 2 + c + 1.0, 0) * _slot(P.USB_C_PLUG)
    # tilt 20 deg toward -Y (the user), then drop onto a wedge so it prints flat
    tilted = Rot(-20, 0, 0) * shelf
    bb = tilted.bounding_box()
    tilted = Pos(0, 0, -bb.min.Z) * tilted
    wedge = Box(ow, bb.size.Y, bb.size.Z, align=_MIN)
    wedge = wedge - Pos(0, 0, 0) * (Rot(-20, 0, 0) * Box(ow + 2, ol * 2, 200, align=(Align.CENTER, Align.CENTER, Align.MIN)))
    part = tilted + wedge
    return part

def build_ion_cradle() -> Part:
    c = P.CLR_DEVICE
    inner_r = M.ION.diameter / 2 + c
    outer_r = inner_r + P.WALL
    h = 25.0
    part = Cylinder(outer_r, h + P.FLOOR, align=_MIN)
    part -= Pos(0, 0, P.FLOOR) * Cylinder(inner_r, h, align=_MIN)
    part -= Pos(M.ION.port_offset_from_axis, 0, 0) * _slot(P.MICRO_PLUG)
    part = chamfer(part.edges().filter_by(Axis.Z, reverse=True).sort_by(Axis.Z)[:1], P.CHAMFER)
    return part

def build_trackr_cradle() -> Part:
    c = P.CLR_DEVICE
    pw = M.TRACKR.width + 2 * c
    pt = M.TRACKR.thickness + 2 * c
    depth = M.TRACKR.length * 0.6
    part = Box(pw + 2 * P.WALL, pt + 2 * P.WALL, depth + P.FLOOR, align=_MIN)
    part -= Pos(0, 0, P.FLOOR) * Box(pw, pt, depth, align=_MIN)
    part -= _slot(P.USB_C_PLUG)
    return part
```

- [ ] **Step 4: Run tests; iterate until green.** The Roam wedge boolean is the most likely to need adjustment: if `is_valid()` fails, replace the wedge subtraction with `split(tilted_box, bisect_by=Plane.XY)` semantics — build the shelf, rotate, then `part = tilted + (Box(ow, bb.size.Y, bb.size.Z, align=_MIN) & Pos(...)*...)`. Keep the tests as the arbiter.

- [ ] **Step 5: Register exports**

In `scripts/export_all.py` add:
```python
from dock import cradles
PARTS.update({
    "cradle_roam": cradles.build_roam_cradle,
    "cradle_ion": cradles.build_ion_cradle,
    "cradle_trackr": cradles.build_trackr_cradle,
})
```
(place after the `PARTS = {...}` definition). Run the script; expect nine new files.

- [ ] **Step 6: Commit**

```bash
git add -A && git commit -m "Add Roam, Ion and Trackr cradles

Co-Authored-By: Claude Fable 5.1 <noreply@anthropic.com>"
```

- [ ] **Step 7: User action:** print the three cradles, check device fit and that each plug sits captive. Adjust `CLR_DEVICE` or measurements, reprint.

---

### Task 5: Divider

**Files:**
- Create: `src/dock/divider.py`, `tests/test_divider.py`
- Modify: `scripts/export_all.py`

**Interfaces:**
- Consumes: `params.CLR_RAIL`.
- Produces: `divider.THICK = 2.0`, `divider.RAIL_W = 4.0`, `divider.RAIL_D = 2.0`, `build_divider(height: float, width: float) -> Part` (a slab with a rectangular rail on each vertical side), and `divider.rail_cutter(height: float) -> Part` returning the mating slot shape to subtract from a bay wall, oriented with the rail's long axis along Z, centred at origin. X (depth) is `RAIL_D + CLR_RAIL` because only the slot bottom bears in X (the bay side is open); Y is `RAIL_W + 2*CLR_RAIL`. deck.py must place the cutter wholly inside the wall: centre at x = ±(SPARE_W/2 + (RAIL_D + CLR_RAIL)/2).

- [ ] **Step 1: Failing test**

`tests/test_divider.py`:
```python
from dock import divider, params

def test_divider_bounding_box():
    p = divider.build_divider(height=40, width=50)
    s = p.bounding_box().size
    assert abs(s.Z - 40) < 1e-6
    assert abs(s.X - (50 + 2 * divider.RAIL_D)) < 1e-6
    assert abs(s.Y - divider.RAIL_W) < 1e-6

def test_cutter_is_larger_than_rail_by_clearance():
    cut = divider.rail_cutter(height=40).bounding_box().size
    assert abs(cut.Y - (divider.RAIL_W + 2 * params.CLR_RAIL)) < 1e-6
```

- [ ] **Step 2: Run, expect failure.**

- [ ] **Step 3: Implement**

`src/dock/divider.py`:
```python
"""Removable divider: 2 mm slab with a rectangular rail on each vertical edge."""
from build123d import Box, Pos, Part, Align
from dock import params as P

THICK = 2.0
RAIL_W = 4.0   # rail width (Y), wider than the slab so it can't pull out sideways
RAIL_D = 2.0   # rail depth into the wall (X)
_MIN = (Align.CENTER, Align.CENTER, Align.MIN)

def build_divider(height: float, width: float) -> Part:
    slab = Box(width, THICK, height, align=_MIN)
    rail = Box(RAIL_D, RAIL_W, height, align=_MIN)
    return slab + Pos(width / 2 + RAIL_D / 2, 0, 0) * rail + Pos(-width / 2 - RAIL_D / 2, 0, 0) * rail

def rail_cutter(height: float) -> Part:
    c = P.CLR_RAIL
    return Box(RAIL_D + c, RAIL_W + 2 * c, height, align=_MIN)
```

- [ ] **Step 4: Run, expect pass.** Register `"divider": lambda: divider.build_divider(40, 50)` in `scripts/export_all.py`.

- [ ] **Step 5: Commit**

```bash
git add -A && git commit -m "Add removable divider with rail cutter

Co-Authored-By: Claude Fable 5.1 <noreply@anthropic.com>"
```

---

### Task 6: Deck

**Files:**
- Create: `src/dock/deck.py`, `tests/test_deck.py`
- Modify: `scripts/export_all.py`

**Interfaces:**
- Consumes: the three cradle builders and `cradle_footprint`; `divider.rail_cutter`; `params.*`; `measurements.CHARGER` (for overall length).
- Produces: `deck.layout() -> dict[str, tuple[float, float]]` giving each cradle's XY centre; `deck.DECK_X, deck.DECK_Y` outer size; `deck.LIP_H = 6.0`; `build_deck() -> Part`; `deck.SPARE_BAY = (x, y, w, l, h)` tuple.

Layout: a single row along X, in order Ion, Roam, Trackr, spare bay, with `params.WALL` gaps. Deck plate thickness = `FLOOR`. The lip is a `WALL`-thick rectangular skirt hanging `LIP_H` below the plate, inset `WALL + CLR_FIT` from the outer edge so it drops into the base. Cable channels are not modelled as separate parts: each cradle's floor slot already passes through the plate, and the underside is open (the base cavity is the cable space).

- [ ] **Step 1: Failing tests**

`tests/test_deck.py`:
```python
from build123d import Axis
from dock import deck, params

def test_deck_fits_bed():
    assert deck.DECK_X <= params.BED_X
    assert deck.DECK_Y <= params.BED_Y

def test_deck_valid_and_flat_on_bed():
    p = deck.build_deck()
    assert p.is_valid()
    assert abs(p.bounding_box().min.Z) < 1e-6

def test_layout_has_four_stations_without_overlap():
    lay = deck.layout()
    assert set(lay) == {"ion", "roam", "trackr", "spare"}
    xs = sorted(v[0] for v in lay.values())
    assert all(b - a > 20 for a, b in zip(xs, xs[1:]))

def test_deck_has_at_least_four_floor_slots():
    p = deck.build_deck()
    bottom = p.faces().sort_by(Axis.Z)[0]
    assert len(bottom.inner_wires()) >= 4
```

- [ ] **Step 2: Run, expect failure.**

- [ ] **Step 3: Implement**

`src/dock/deck.py`:
```python
"""Top deck: plate + lip + three cradles + spare bay with divider slots."""
from build123d import Box, Pos, Part, Align, Rot
from dock import params as P
from dock import measurements as M
from dock import cradles, divider

_MIN = (Align.CENTER, Align.CENTER, Align.MIN)
LIP_H = 6.0
SPARE_W, SPARE_L, SPARE_H = 40.0, 70.0, 30.0   # X, Y, wall height

def _stations() -> list[tuple[str, float, float]]:
    """(name, x_size, y_size) in row order."""
    ion = cradles.cradle_footprint(cradles.build_ion_cradle())
    roam = cradles.cradle_footprint(cradles.build_roam_cradle())
    trk = cradles.cradle_footprint(cradles.build_trackr_cradle())
    return [("ion", *ion), ("roam", *roam), ("trackr", *trk),
            ("spare", SPARE_W + 2 * P.WALL, SPARE_L + 2 * P.WALL)]

def layout() -> dict[str, tuple[float, float]]:
    x = P.WALL
    out = {}
    for name, sx, _ in _stations():
        out[name] = (x + sx / 2, 0.0)
        x += sx + P.WALL
    return out

DECK_X = P.WALL + sum(s[1] + P.WALL for s in _stations())
DECK_Y = max(s[2] for s in _stations()) + 2 * P.WALL

def _spare_bay() -> Part:
    bay = Box(SPARE_W + 2 * P.WALL, SPARE_L + 2 * P.WALL, SPARE_H + P.FLOOR, align=_MIN)
    bay -= Pos(0, 0, P.FLOOR) * Box(SPARE_W, SPARE_L, SPARE_H, align=_MIN)
    bay -= Pos(0, 0, 0) * Box(P.USB_A_PLUG.width + 2 * P.CLR_DEVICE,
                              P.USB_A_PLUG.height + 2 * P.CLR_DEVICE, 100,
                              align=(Align.CENTER, Align.CENTER, Align.CENTER))
    # two divider positions, rails cut into both long walls
    for y in (-SPARE_L / 4, SPARE_L / 4):
        for x in (SPARE_W / 2 + (divider.RAIL_D + P.CLR_RAIL) / 2, -(SPARE_W / 2 + (divider.RAIL_D + P.CLR_RAIL) / 2)):
            bay -= Pos(x, y, P.FLOOR) * divider.rail_cutter(SPARE_H)
    return bay

def build_deck() -> Part:
    plate = Box(DECK_X, DECK_Y, P.FLOOR, align=(Align.MIN, Align.CENTER, Align.MIN))
    lip_out = Box(DECK_X - 2 * (P.WALL + P.CLR_FIT), DECK_Y - 2 * (P.WALL + P.CLR_FIT), LIP_H,
                  align=(Align.MIN, Align.CENTER, Align.MAX))
    lip_in = Box(DECK_X - 2 * (2 * P.WALL + P.CLR_FIT), DECK_Y - 2 * (2 * P.WALL + P.CLR_FIT), LIP_H,
                 align=(Align.MIN, Align.CENTER, Align.MAX))
    lip = Pos(P.WALL + P.CLR_FIT, 0, 0) * lip_out - Pos(2 * P.WALL + P.CLR_FIT, 0, 0) * lip_in
    deck = plate + lip
    builders = {"ion": cradles.build_ion_cradle, "roam": cradles.build_roam_cradle,
                "trackr": cradles.build_trackr_cradle, "spare": _spare_bay}
    for name, (x, y) in layout().items():
        cradle = builders[name]()
        # cradles carry their own FLOOR; sink them so their floor merges with the plate
        deck += Pos(x, y, 0) * cradle
        # re-cut the cradle's floor slot through the plate
        slot_faces = cradle.faces().sort_by(lambda f: f.center().Z)[0].inner_wires()
        for w in slot_faces:
            bb = w.bounding_box()
            deck -= Pos(x + bb.center().X, y + bb.center().Y, 0) * Box(
                bb.size.X, bb.size.Y, 100, align=(Align.CENTER, Align.CENTER, Align.CENTER))
    # lift everything so the lip bottom is at Z=0 (prints deck-up with the lip as a skirt)
    return Pos(0, 0, LIP_H) * deck
```

Note: this prints deck-side up with the 6 mm lip as a skirt, which needs no support; cradle pockets face up. Slots through the plate are 100 mm tall cutters so they pass the lip region too.

- [ ] **Step 4: Run tests; fix until green.** Register `"deck": deck.build_deck` in `scripts/export_all.py`.

- [ ] **Step 5: Commit**

```bash
git add -A && git commit -m "Add deck with cradles, spare bay and lip

Co-Authored-By: Claude Fable 5.1 <noreply@anthropic.com>"
```

---

### Task 7: Base tray

**Files:**
- Create: `src/dock/base.py`, `tests/test_base.py`
- Modify: `scripts/export_all.py`

**Interfaces:**
- Consumes: `deck.DECK_X, DECK_Y, PLATE_T`; `measurements.CHARGER`; `params.*`.
- Produces: `base.BASE_H`, `base.BASE_X`, `base.BASE_Y`, `base.REBATE_D`, `build_base() -> Part`.

Geometry (rebate design, per the Task 6 ruling: the deck is a flat 8 mm plate, no lip): open-top box with outer size `BASE_X = DECK_X + 2*(WALL + CLR_FIT)`, `BASE_Y = DECK_Y + 2*(WALL + CLR_FIT)`, walls `WALL`, floor `FLOOR`. Inner height below the plate = `CHARGER.height + 12` (cable bend room). At the top of the inner walls a rebate `REBATE_D = PLATE_T` deep and `CLR_FIT` wider than the deck on each side receives the plate flush with the base top; the walls below the rebate are `2*WALL` thick so the plate rests on a `WALL`-wide ledge. `BASE_H = FLOOR + CHARGER.height + 12 + PLATE_T`. Charger fence: a raised `WALL`-thick fence inside the floor, `CHARGER + 2*CLR_FIT` in plan, 8 mm tall, port face toward +X, with a fingernail notch. Rear (-Y) wall cut-outs: AC cord notch (10 mm wide, from the top edge down to `inlet_center_z`), escape port (`USB_A_PLUG.width + 4` wide, 12 mm tall, just below the rebate), LED window 4 mm square at the LED position. Four 10 mm diameter, 1 mm deep foot recesses underneath.

- [ ] **Step 1: Failing tests**

`tests/test_base.py`:
```python
from build123d import Axis
from dock import base, deck, params
from dock import measurements as m

def test_base_outer_size_wraps_deck_with_clearance():
    bb = base.build_base().bounding_box().size
    assert abs(bb.X - (deck.DECK_X + 2 * (params.WALL + params.CLR_FIT))) < 1e-6
    assert abs(bb.Y - (deck.DECK_Y + 2 * (params.WALL + params.CLR_FIT))) < 1e-6

def test_base_height_leaves_charger_room_under_plate():
    assert base.BASE_H >= params.FLOOR + m.CHARGER.height + deck.PLATE_T

def test_rebate_depth_matches_plate():
    assert abs(base.REBATE_D - deck.PLATE_T) < 1e-6

def test_base_valid_and_on_bed():
    p = base.build_base()
    assert p.is_valid
    assert abs(p.bounding_box().min.Z) < 1e-6

def test_base_has_four_foot_recesses():
    p = base.build_base()
    bottom = p.faces().sort_by(Axis.Z)[0]
    assert len(bottom.inner_wires()) == 4
```

- [ ] **Step 2: Run, expect failure.**

- [ ] **Step 3: Implement**

`src/dock/base.py`:
```python
"""Base tray: hides the Anker PowerPort 6 and the cable slack; the deck plate drops into a top rebate."""
from build123d import Box, Cylinder, Pos, Part, Align
from dock import params as P
from dock import measurements as M
from dock import deck

_MIN = (Align.CENTER, Align.CENTER, Align.MIN)
CABLE_ROOM = 12.0
FENCE_H = 8.0
REBATE_D = deck.PLATE_T
BASE_X = deck.DECK_X + 2 * (P.WALL + P.CLR_FIT)
BASE_Y = deck.DECK_Y + 2 * (P.WALL + P.CLR_FIT)
BASE_H = P.FLOOR + M.CHARGER.height + CABLE_ROOM + REBATE_D

def build_base() -> Part:
    X, Y = BASE_X, BASE_Y
    cx = X / 2
    body = Pos(cx, 0, 0) * Box(X, Y, BASE_H, align=_MIN)
    # lower cavity: walls 2*WALL thick so the rebate leaves a WALL-wide ledge
    body -= Pos(cx, 0, P.FLOOR) * Box(X - 4 * P.WALL, Y - 4 * P.WALL, BASE_H, align=_MIN)
    # rebate that receives the deck plate flush with the top
    body -= Pos(cx, 0, BASE_H - REBATE_D) * Box(
        deck.DECK_X + 2 * P.CLR_FIT, deck.DECK_Y + 2 * P.CLR_FIT, REBATE_D, align=_MIN)

    # charger fence, port face toward +X, charger centred in Y
    ch_l, ch_w = M.CHARGER.length + 2 * P.CLR_FIT, M.CHARGER.width + 2 * P.CLR_FIT
    fence = Box(ch_l + 2 * P.WALL, ch_w + 2 * P.WALL, FENCE_H + P.FLOOR, align=_MIN)
    fence -= Pos(0, 0, P.FLOOR) * Box(ch_l, ch_w, FENCE_H, align=_MIN)
    fence -= Pos(0, ch_w / 2, P.FLOOR) * Box(20, 2 * P.WALL + 2, FENCE_H, align=_MIN)  # nail notch
    fence_x = 2 * P.WALL + P.WALL + ch_l / 2
    body += Pos(fence_x, 0, 0) * fence

    # rear wall (-Y): cord notch above the inlet, escape port, LED window
    rear_y = -Y / 2
    inlet_x = fence_x - ch_l / 2  # inlet face is on the -X side of the charger
    body -= Pos(inlet_x, rear_y, P.FLOOR + M.CHARGER.inlet_center_z) * Box(10, 3 * P.WALL, BASE_H, align=_MIN)
    body -= Pos(X - 30, rear_y, BASE_H - REBATE_D - 12) * Box(P.USB_A_PLUG.width + 4, 3 * P.WALL, 12, align=_MIN)
    led_x = fence_x + ch_l / 2 - M.CHARGER.port_face_margin - M.CHARGER.led_offset_from_ports
    body -= Pos(led_x, rear_y, P.FLOOR + M.CHARGER.height / 2) * Box(4, 3 * P.WALL, 4, align=_MIN)

    # foot recesses
    for fx in (12, X - 12):
        for fy in (-Y / 2 + 12, Y / 2 - 12):
            body -= Pos(fx, fy, 0) * Cylinder(5, 1.0, align=_MIN)
    return body
```

Note: the cord notch runs up through the rebate ledge at the rear; that is intended (the cord drops in from above before the plate is seated). If the tests find the rear-wall cuts merge inner wires on the bottom face, move the foot recesses inboard.

- [ ] **Step 4: Run tests until green.** Register `"base": base.build_base`.

- [ ] **Step 5: Commit**

```bash
git add -A && git commit -m "Add base tray with rebate, charger fence, cord notch, escape port

Co-Authored-By: Claude Fable 5.1 <noreply@anthropic.com>"
```

---

### Task 8: Assembly checks and print handoff

**Files:**
- Create: `tests/test_assembly.py`, `docs/printing.md`
- Modify: `README.md`

**Interfaces:**
- Consumes: `deck.build_deck`, `deck.DECK_X/DECK_Y/PLATE_T`, `base.build_base`, `base.BASE_H/BASE_X/BASE_Y/REBATE_D`, `params.CLR_FIT/WALL/BED_X/BED_Y`.

- [ ] **Step 1: Failing tests**

`tests/test_assembly.py`:
```python
from build123d import Pos
from dock import deck, base, params

def test_plate_fits_rebate_with_clearance():
    assert base.BASE_X - 2 * params.WALL >= deck.DECK_X + 2 * params.CLR_FIT - 1e-6
    assert base.BASE_Y - 2 * params.WALL >= deck.DECK_Y + 2 * params.CLR_FIT - 1e-6

def test_assembled_parts_do_not_intersect():
    d = deck.build_deck()
    b = base.build_base()
    seated = Pos(params.WALL + params.CLR_FIT, 0, base.BASE_H - base.REBATE_D) * d
    inter = seated & b
    assert inter.volume < 1e-3

def test_plate_top_is_flush_with_base_top():
    assert abs((base.BASE_H - base.REBATE_D + deck.PLATE_T) - base.BASE_H) < 1e-6

def test_assembled_footprint_within_bed():
    assert base.BASE_X <= params.BED_X and base.BASE_Y <= params.BED_Y
```

- [ ] **Step 2: Run; fix geometry until green.**

- [ ] **Step 3: Printing guide**

`docs/printing.md`:
```markdown
# Printing on the Snapmaker U1

Slicer: Snapmaker Orca (Flatpak `io.github.Snapmaker.Snapmaker_Orca`).
Material: PETG. Profile: U1 0.4 nozzle, 0.2 mm layers.

| Part | Orientation | Walls | Infill | Supports |
|---|---|---|---|---|
| coupon_plate, coupon_peg | as exported | 3 | 15 % | none |
| cradle_* | as exported (pocket up) | 3 | 15 % | none |
| divider | as exported | 3 | 100 % | none |
| deck | as exported (flat plate on bed, cradles up) | 3 | 15 % | none |
| base | as exported (open top up) | 3 | 15 % | none |

Order: coupon → update `params.py` → cradles → deck → base.
Run `uv run python scripts/export_all.py` after any parameter change; open
`out/<part>.3mf` in the slicer.
```

- [ ] **Step 4: Update README** with a "Workflow" section pointing to `docs/measuring.md` and `docs/printing.md`.

- [ ] **Step 5: Commit**

```bash
git add -A && git commit -m "Add assembly fit tests and printing guide

Co-Authored-By: Claude Fable 5.1 <noreply@anthropic.com>"
```

---

## Self-review

- Spec coverage: base (T7), deck (T6), cradles (T4), divider (T5), coupon (T2), measurements (T3), export/tests/toolchain (T1), bed limit (T6/T8), LED window and escape port and cord notch (T7), rubber feet (T7). Corner pegs from the spec were dropped in favour of the lip alone (noted in T7); snap-in cable channels were dropped because the open base cavity is the cable space (noted in T6). Both are simplifications the executor should keep unless the fit test shows the deck rocking.
- Placeholders: none. Nominal measurement defaults are explicit values marked NOMINAL and replaced by the user.
- Type consistency: `build_*() -> Part` everywhere; `cradle_footprint`, `rail_cutter(height)`, `layout()`, `DECK_X/DECK_Y/LIP_H/BASE_H` names match across tasks.

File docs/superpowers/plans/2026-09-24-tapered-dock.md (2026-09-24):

# Tapered Dock (physical v2) Implementation Plan

> **For agentic workers:** REQUIRED SUB-SKILL: Use superpowers:subagent-driven-development (recommended) or superpowers:executing-plans to implement this plan task-by-task. Steps use checkbox (`- [ ]`) syntax for tracking.

**Goal:** Replace the v1 box dock with the tapered, hinged, two-tone dock of the spec, at least 25 % cheaper to print than v1 in both time and filament.

**Architecture:** Two new number/geometry helpers carry the shared shape: `taper.py` (the 15° drafted rounded outline) and `layout.py` (bay rectangles, outlines, heights, as numbers). `hinge.py` builds both halves of the snap-on hinge in base coordinates. `tray.py`, `base.py` and `lid.py` are rewritten on top of those, one per task, each replacing its v1 module and v1 tests; the removable divider goes. Every code block below was built and its tests run green in a scratch worktree during planning (95 tests at the end state).

**Tech Stack:** Python 3.12, build123d 0.12 (algebra API), pytest, uv; Snapmaker Orca Flatpak for slicing.

**Spec:** docs/superpowers/specs/2026-09-23-tapered-dock-design.md

## Global Constraints

- Python 3.12 through uv only: `uv run pytest`, `uv run python scripts/...`. Never system Python.
- All dimensions in mm. Design rules in `src/dock/params.py`; caliper inputs in `src/dock/measurements.py`; never inline a number that belongs there.
- One `build_*()` per printed part; each part's bed face at Z = 0; XY centred and shared by all parts.
- Tests measure the built solid (faces, bounding boxes, intersections, probes), never restate a constant.
- Every downward face ≤ 45° off vertical, except allowlisted bridges ≤ 20 mm and the one supported ceiling (the cord port). Chamfers, not fillets, on downward edges.
- `out/` is gitignored; never commit exports.
- Work on branch `tapered-dock`. Commit after every task, with the trailer line `Co-Authored-By: Claude Opus 5.5 <noreply@anthropic.com>`.
- After every task, `uv run pytest` is fully green.
- Design values (spec): TAPER_DEG 15, CORNER_R 30 (rim), BAND_H 8, WALL 2.0, THIN_WALL 1.6, FLOOR 1.2, TRAY_PLATE 1.2, LID_PLATE 1.2, CLR_BAY 8, CLR_BAY_OUTER 3, BAY_DEPTH 38, BED 250 × 250.

## File structure

| File | Status | Responsibility |
|---|---|---|
| `scripts/slice_report.py` | new | Headless Orca slice of out/*.stl, time and grams vs the v1 baseline |
| `src/dock/params.py` | modify | v2 design rules (temporary `V1_*` shims until Task 6) |
| `src/dock/measurements.py` | modify | `Charger.corner_r` |
| `src/dock/taper.py` | new | 15° draft, `Outline`, `corner_rect`, `horiz`, `bed_chamfer_inset` |
| `src/dock/layout.py` | new | Bays, device footprints, cutouts, heights, tray/rim outlines, lid lip |
| `src/dock/hinge.py` | new | Axis, pins/cheeks, hooks, heel, relief discs, `opened()` |
| `src/dock/coupon.py` | modify | + `build_hinge_coupon()` |
| `src/dock/lid.py` | rewrite | Tapered hinged lid, `build_lid()`, `lid_seat(deg)` |
| `src/dock/base.py` | rewrite | Tapered two-tone base, ledge, fence, ports, hinge pins, `tray_seat()` |
| `src/dock/tray.py` | rewrite | Tapered tray, fixed filleted dividers, finger slot |
| `src/dock/divider.py` | delete | (dividers are now fixed) |
| `scripts/export_all.py` | modify | PARTS and a bounding-box build report |
| `tests/printability.py` | new | `steep_faces`, `span`, `overhang_deg` helpers |
| `tests/test_taper.py`, `test_layout.py`, `test_hinge.py` | new | |
| `tests/test_lid.py`, `test_base.py`, `test_tray.py`, `test_assembly.py` | rewrite | |
| `tests/test_divider.py` | delete | |
| `tests/test_params.py`, `test_measurements.py`, `test_coupon.py` | modify | |
| `docs/printing.md`, `docs/measuring.md`, `CLAUDE.md` | modify | |

Test files import sibling helpers (`from printability import ...`); pytest's default rootdir-prepend import mode puts `tests/` on the path, so no `__init__.py` or conftest is needed.

---

### Task 1: Slice report

**Files:**
- Create: `scripts/slice_report.py`

**Interfaces:**
- Produces: `uv run python scripts/slice_report.py [--layer 0.20|0.28] [STL ...]` → prints a part | time | grams table, a total, and (with no STL arguments) the v2-set-vs-v1-set percentages. Writes only under `out/slice/`.

Not TDD: it drives the Flatpak and takes minutes, so it is verified by reproducing the v1 baseline.

- [ ] **Step 1: Write the script**

```python
"""Slice the exported parts headlessly in Snapmaker Orca and report print
time and filament for each, next to the v1 baseline.

    uv run python scripts/slice_report.py                  # 0.20 Standard, the dock set in out/
    uv run python scripts/slice_report.py --layer 0.28     # 0.28 Extra Draft
    uv run python scripts/slice_report.py releases/v1-prototype/tray.stl

It needs the Snapmaker Orca Flatpak and takes minutes, so it is not part of
pytest.  The profiles are the vendor's own -- Snapmaker U1 (0.4 nozzle), the
0.20 Standard or 0.28 Extra Draft process, Generic PETG -- flattened at run
time, with the per-part settings from docs/printing.md laid over them: three
walls and 15 % infill everywhere, supports only for the base.

The Orca CLI in this Flatpak has three quirks, each handled below:
- system profiles `inherits` from one another and the CLI will not follow
  the chain, so each is flattened into one standalone JSON first -- keeping
  `"from": "system"`, because a flattened "User" process is then reported as
  incompatible with the printer (return code -17);
- any process carrying the key `wipe_tower_filament` segfaults it (exit 139),
  so that key is dropped;
- `--export-3mf` is joined onto `--outputdir`, so it gets a bare file name.
The estimates are read from the gcode header inside the exported 3mf.
"""
import argparse
import json
import re
import subprocess
import sys
import zipfile
from pathlib import Path

APP = "io.github.Snapmaker.Snapmaker_Orca"
MACHINE = "Snapmaker U1 (0.4 nozzle)"
PROCESS = {"0.20": "0.20 Standard @Snapmaker U1 (0.4 nozzle)",
           "0.28": "0.28 Extra Draft @Snapmaker U1 (0.4 nozzle)"}
FILAMENT = "Generic PETG"
SUPPORTED = {"base"}             # parts that print with supports
DOCK_SET = ("base", "tray", "lid")
# The v1 prototype's STLs (releases/v1-prototype/) through this same script
# at 0.20, 2026-09-24: (minutes, grams) per part, and how many of each part a
# v1 set needed.  Re-run it on those STLs if the Flatpak's profiles change.
BASELINE = {"base": (355, 263.7), "tray": (262, 184.5), "lid": (135, 103.8),
            "divider": (44, 15.2)}
BASELINE_COUNT = {"base": 1, "tray": 1, "lid": 1, "divider": 2}
OUT = Path("out/slice")

def _profiles_root() -> Path:
    loc = subprocess.run(["flatpak", "info", "--show-location", APP],
                         capture_output=True, text=True, check=True).stdout.strip()
    return Path(loc) / "files/share/Snapmaker_Orca/profiles"

def _index(root: Path, kind: str) -> dict[str, Path]:
    """name -> file for every `kind` (machine/process/filament) profile."""
    idx: dict[str, Path] = {}
    for fp in root.rglob(f"{kind}/*.json"):
        try:
            name = json.loads(fp.read_text()).get("name")
        except (json.JSONDecodeError, UnicodeDecodeError):
            continue
        if name and name not in idx:
            idx[name] = fp
    return idx

def _flatten(idx: dict[str, Path], name: str) -> dict:
    d = json.loads(idx[name].read_text())
    parent = d.pop("inherits", None)
    merged = _flatten(idx, parent) if parent else {}
    merged.update(d)
    merged["from"] = "system"
    merged.pop("inherits", None)
    return merged

def _write(d: dict, path: Path) -> Path:
    path.write_text(json.dumps(d, indent=4))
    return path.resolve()

def _minutes(text: str) -> float:
    total = 0.0
    for n, unit in re.findall(r"(\d+)([dhms])", text):
        total += int(n) * {"d": 1440, "h": 60, "m": 1, "s": 1 / 60}[unit]
    return total

def _estimates(threemf: Path) -> tuple[float, float]:
    with zipfile.ZipFile(threemf) as z:
        gcode = next(n for n in z.namelist() if n.endswith(".gcode"))
        head = z.read(gcode).decode(errors="replace")
    t = re.search(r"estimated printing time \(normal mode\) = ([^\n]+)", head)
    g = re.search(r"total filament used \[g\] = ([\d.]+)", head)
    if not (t and g):
        raise RuntimeError(f"no estimates in {threemf}")
    return _minutes(t.group(1)), float(g.group(1))

def slice_part(stl: Path, layer: str, prof: dict[str, Path]) -> tuple[float, float]:
    name = stl.stem
    outdir = (OUT / f"{name}_{layer}").resolve()
    outdir.mkdir(parents=True, exist_ok=True)
    process = prof["support" if name in SUPPORTED else "plain"]
    cmd = ["flatpak", "run", f"--filesystem={OUT.resolve()}",
           f"--filesystem={stl.resolve().parent}", APP,
           "--load-settings", f"{prof['machine']};{process}",
           "--load-filaments", str(prof["filament"]),
           "--slice", "0", "--export-3mf", f"{name}.3mf",
           "--outputdir", str(outdir), str(stl.resolve())]
    run = subprocess.run(cmd, capture_output=True, text=True)
    result = outdir / "result.json"
    rc = json.loads(result.read_text()).get("return_code") if result.exists() else None
    if run.returncode != 0 or rc not in (0, None):
        raise RuntimeError(f"{name}: orca exit {run.returncode}, return_code {rc}\n"
                           f"{run.stderr[-2000:]}")
    return _estimates(outdir / f"{name}.3mf")

def _fmt(minutes: float) -> str:
    return f"{int(minutes // 60)}h{int(round(minutes % 60)):02d}"

def main() -> int:
    ap = argparse.ArgumentParser(description=__doc__.split("\n")[0])
    ap.add_argument("stls", nargs="*", type=Path)
    ap.add_argument("--layer", choices=sorted(PROCESS), default="0.20")
    args = ap.parse_args()
    stls = args.stls or [Path("out") / f"{n}.stl" for n in DOCK_SET]
    missing = [s for s in stls if not s.exists()]
    if missing:
        print(f"missing: {', '.join(map(str, missing))} -- run scripts/export_all.py",
              file=sys.stderr)
        return 1

    OUT.mkdir(parents=True, exist_ok=True)
    root = _profiles_root()
    proc = _flatten(_index(root, "process"), PROCESS[args.layer])
    proc.pop("wipe_tower_filament", None)
    proc.update({"wall_loops": "3", "sparse_infill_density": "15%"})
    prof = {
        "machine": _write(_flatten(_index(root, "machine"), MACHINE), OUT / "machine.json"),
        "filament": _write(_flatten(_index(root, "filament"), FILAMENT), OUT / "filament.json"),
        "plain": _write({**proc, "enable_support": "0"}, OUT / f"process_{args.layer}.json"),
        "support": _write({**proc, "enable_support": "1"}, OUT / f"process_{args.layer}_s.json"),
    }

    total_t = total_g = 0.0
    print(f"slice report: {PROCESS[args.layer]}, {FILAMENT}")
    print(f"  {'part':<10}{'time':>8}{'grams':>9}   v1 time   v1 g")
    for stl in stls:
        t, g = slice_part(stl, args.layer, prof)
        total_t, total_g = total_t + t, total_g + g
        base = BASELINE.get(stl.stem)
        ref = f"   {_fmt(base[0]):>7}{base[1]:7.1f}" if base else ""
        print(f"  {stl.stem:<10}{_fmt(t):>8}{g:9.1f}{ref}")
    v1_t = sum(BASELINE[n][0] * c for n, c in BASELINE_COUNT.items())
    v1_g = sum(BASELINE[n][1] * c for n, c in BASELINE_COUNT.items())
    print(f"  {'total':<10}{_fmt(total_t):>8}{total_g:9.1f}   {_fmt(v1_t):>7}{v1_g:7.1f}")
    if not args.stls:
        print(f"  v2 set vs v1 set: time {100 * (total_t / v1_t - 1):+.0f} %, "
              f"filament {100 * (total_g / v1_g - 1):+.0f} %")
    return 0

if __name__ == "__main__":
    sys.exit(main())
```

- [ ] **Step 2: Reproduce the v1 baseline**

Run: `uv run python scripts/slice_report.py releases/v1-prototype/tray.stl releases/v1-prototype/lid.stl releases/v1-prototype/base.stl releases/v1-prototype/divider.stl`
Expected (±1 %): tray 4h22 184.5 g, lid 2h15 103.8 g, base 5h55 263.7 g, divider 0h44 15.2 g. If the Flatpak's profiles changed and these moved, update `BASELINE` from this run and say so in the commit message.

- [ ] **Step 3: Commit**

```bash
git add scripts/slice_report.py
git commit -m "Slice report: headless Orca time and grams against the v1 baseline"
```

---

### Task 2: Design rules, charger corner, taper and layout

**Files:**
- Modify: `src/dock/params.py`, `src/dock/measurements.py`, `docs/measuring.md`
- Modify (mechanical rename only): `src/dock/base.py`, `src/dock/tray.py`, `src/dock/lid.py`, `src/dock/divider.py`, `tests/test_base.py`, `tests/test_tray.py`, `tests/test_lid.py`, `tests/test_assembly.py`, `tests/test_divider.py`
- Create: `src/dock/taper.py`, `src/dock/layout.py`, `tests/test_taper.py`, `tests/test_layout.py`
- Test: `tests/test_params.py`, `tests/test_measurements.py`

**Interfaces:**
- Produces: `params` v2 names (above); `measurements.Charger.corner_r` (float, default 6.0); `taper.TAN`, `taper.COS`, `taper.horiz(t)`, `taper.bed_chamfer_inset()`, `taper.Outline(sx, sy, r, z_ref)` with `.at(z, inset=0) -> (sx, sy, r)`, `.section(z, inset=0) -> Sketch`, `.solid(z0, z1, inset=0) -> Part`; `taper.corner_rect(x0, x1, y0, y1, radii: dict[str, float], z) -> Sketch` (keys "--", "+-", "++", "-+"); `layout.Bay` (name, x0, x1, y0, y1, sloped: (−X, +X, −Y, +Y), .cx, .cy), `layout.BAYS` (roam, spare, trackr, ion), `layout.DEVICES`, `layout.device_footprint(name) -> (x0, x1, y0, y1)`, `layout.cutouts() -> [(bay, cx, cy, sx, sy)]`, `layout.TRAY_H`, `BASE_H`, `TRAY_Z0`, `TRAY_OUTLINE`, `RIM`, `LIP_W`, `LID_H`, `LID_SLOPE_H`, `LIP_H`, `TRAY_SINK`, `TRAY_GAP`, `INNER_FILLET_R`, `FLOOR_FILLET_R`, `CUTOUT`, `CUTOUT_INSET`, `UNDERSIDE_PORT_CUTOUTS`, `FLOOR_X`, `FLOOR_Y`.

The v1 modules still use `WALL`, `FLOOR`, `CORNER_R` and `TRAY_PLATE`, whose values change here. To keep v1 building (and its tests green) until each module is replaced, they are renamed to `V1_*` copies holding the old values.

- [ ] **Step 1: Write the failing tests**

`tests/test_taper.py`:

```python
import math

from build123d import Axis, GeomType

from dock import params, taper

def _circle_radii(face):
    return sorted({round(e.radius, 3) for e in face.edges()
                   if e.geom_type == GeomType.CIRCLE})

def test_the_draft_is_the_spec_angle():
    assert math.isclose(math.degrees(math.atan(taper.TAN)), params.TAPER_DEG)

def test_a_drafted_solid_leans_by_the_draft_on_every_side():
    o = taper.Outline(100.0, 60.0, 20.0, z_ref=50.0)
    p = o.solid(10.0, 50.0)
    faces = p.faces().sort_by(Axis.Z)
    bottom, top = faces[0].bounding_box().size, faces[-1].bounding_box().size
    lean = 40.0 * math.tan(math.radians(params.TAPER_DEG))
    assert math.isclose(top.X - bottom.X, 2 * lean, abs_tol=1e-4)
    assert math.isclose(top.Y - bottom.Y, 2 * lean, abs_tol=1e-4)

def test_the_corner_radius_shrinks_with_the_draft_so_corners_stay_concentric():
    o = taper.Outline(100.0, 60.0, 20.0, z_ref=50.0)
    p = o.solid(10.0, 50.0)
    faces = p.faces().sort_by(Axis.Z)
    lean = 40.0 * taper.TAN
    assert _circle_radii(faces[-1]) == [20.0]
    assert _circle_radii(faces[0]) == [round(20.0 - lean, 3)]

def test_an_inset_outline_is_a_wall_thickness_in_from_it():
    o = taper.Outline(100.0, 60.0, 20.0, z_ref=50.0)
    outer = o.solid(0.0, 50.0).faces().sort_by(Axis.Z)[-1].bounding_box().size
    inner = o.solid(0.0, 50.0, inset=taper.horiz(2.0)).faces().sort_by(Axis.Z)[-1].bounding_box().size
    # measured square to the drafted face, the wall is 2.0 thick
    assert math.isclose((outer.X - inner.X) / 2 * taper.COS, 2.0, abs_tol=1e-4)

def test_above_its_reference_height_an_outline_grows():
    o = taper.Outline(100.0, 60.0, 20.0, z_ref=0.0)
    sx, sy, r = o.at(10.0)
    assert sx > 100.0 and sy > 60.0 and r > 20.0

def test_corner_rect_rounds_each_corner_by_its_own_radius():
    s = taper.corner_rect(0, 40, 0, 30, {"--": 10.0, "+-": 3.0, "++": 0.0, "-+": 5.0}, z=0)
    assert _circle_radii(s.faces()[0]) == [3.0, 5.0, 10.0]

def test_bed_chamfer_inset_makes_a_45_degree_foot_on_a_drafted_wall():
    o = taper.Outline(100.0, 60.0, 20.0, z_ref=50.0)
    lo = o.at(0.0, taper.bed_chamfer_inset())[0]
    hi = o.at(params.CHAMFER)[0]
    assert math.isclose((hi - lo) / 2, params.CHAMFER, abs_tol=1e-9)
```

`tests/test_layout.py`:

```python
"""The layout is numbers, so these check the relations the parts rely on:
bays tile the tray floor, devices fit their bays, the stack-up adds up."""
import math

from dock import measurements as m
from dock import layout as L, params, taper

def test_the_four_bays_tile_the_tray_floor_with_wall_thick_gaps():
    b = L.BAYS
    assert math.isclose(b["spare"].x0 - b["roam"].x1, params.WALL)
    assert math.isclose(b["trackr"].y0 - b["spare"].y1, params.WALL)
    assert math.isclose(b["ion"].y0 - b["trackr"].y1, params.WALL)
    assert math.isclose(b["roam"].x0, -L.FLOOR_X / 2)
    assert math.isclose(b["spare"].x1, L.FLOOR_X / 2)
    for bay in b.values():
        assert bay.y0 >= -L.FLOOR_Y / 2 - 1e-9 and bay.y1 <= L.FLOOR_Y / 2 + 1e-9

def test_a_bay_side_is_sloped_exactly_when_it_is_on_the_floor_outline():
    for bay in L.BAYS.values():
        on_edge = (math.isclose(bay.x0, -L.FLOOR_X / 2), math.isclose(bay.x1, L.FLOOR_X / 2),
                   math.isclose(bay.y0, -L.FLOOR_Y / 2), math.isclose(bay.y1, L.FLOOR_Y / 2))
        assert bay.sloped == on_edge, bay.name

def test_each_device_sits_inside_its_bay_with_its_clearances():
    for name in L.DEVICES:
        bay = L.BAYS[name]
        x0, x1, y0, y1 = L.device_footprint(name)
        sides = (x0 - bay.x0, bay.x1 - x1, y0 - bay.y0, bay.y1 - y1)
        for gap, sloped in zip(sides, bay.sloped):
            need = params.CLR_BAY_OUTER if sloped else params.CLR_BAY
            assert gap >= need - 1e-9, (name, gap, need)

def test_cutouts_sit_in_their_bays_clear_of_the_floor_fillet_and_the_device():
    for name, cx, cy, sx, sy in L.cutouts():
        bay = L.BAYS[name]
        assert bay.x0 + L.FLOOR_FILLET_R < cx - sx / 2 and cx + sx / 2 < bay.x1 - L.FLOOR_FILLET_R
        assert bay.y0 + L.FLOOR_FILLET_R < cy - sy / 2 and cy + sy / 2 < bay.y1 - L.FLOOR_FILLET_R
        if name in L.DEVICES and name not in L.UNDERSIDE_PORT_CUTOUTS:
            x0, x1, y0, y1 = L.device_footprint(name)
            clear_x = cx + sx / 2 <= x0 or cx - sx / 2 >= x1
            clear_y = cy + sy / 2 <= y0 or cy - sy / 2 >= y1
            assert clear_x or clear_y, name

def test_six_cutouts_three_under_the_ion():
    names = [c[0] for c in L.cutouts()]
    assert len(names) == 6 and names.count("ion") == 3

def test_the_stack_up_puts_the_tray_on_the_cable_room_above_the_charger():
    assert math.isclose(L.TRAY_Z0, params.FLOOR + m.CHARGER.height + L.CABLE_ROOM)
    assert math.isclose(L.TRAY_Z0 + L.TRAY_H + L.TRAY_SINK, L.BASE_H)

def test_the_tray_and_the_rim_share_corner_centres():
    t, r = L.TRAY_OUTLINE, L.RIM
    at_rim = t.at(L.TRAY_H + L.TRAY_SINK)   # the tray outline carried up to rim height
    assert math.isclose(r.sx / 2 - r.r, at_rim[0] / 2 - at_rim[2], abs_tol=1e-9)

def test_the_tray_floor_outline_is_the_bays_plus_a_thin_wall():
    sx, sy, _ = L.TRAY_OUTLINE.at(params.TRAY_PLATE)
    assert math.isclose(sx, L.FLOOR_X + 2 * taper.horiz(params.THIN_WALL))
    assert math.isclose(sy, L.FLOOR_Y + 2 * taper.horiz(params.THIN_WALL))

def test_the_lid_lip_keeps_at_least_a_millimetre_inside_the_bed():
    assert 1.0 <= L.LIP_W <= L.LIP_W_MAX
```

Replace `test_design_rules_match_spec` in `tests/test_params.py` with:

```python
def test_design_rules_match_spec():
    assert params.WALL == 2.0
    assert params.THIN_WALL == 1.6
    assert params.FLOOR == 1.2
    assert params.CLR_FIT == 0.15
    assert params.CLR_BAY == 8.0
    assert params.CLR_BAY_OUTER == 3.0
    assert params.TRAY_PLATE == 1.2
    assert params.LID_PLATE == 1.2
    assert params.BAY_DEPTH == 38.0
    assert params.TAPER_DEG == 15.0
    assert params.CORNER_R == 30.0
    assert params.BAND_H == 8.0
    assert (params.BED_X, params.BED_Y) == (250, 250)
```

Append to `tests/test_measurements.py`:

```python
def test_the_charger_corner_radius_fits_the_body():
    c = m.CHARGER
    assert 0 < c.corner_r < min(c.port_face_width, c.port_to_inlet) / 2
```

- [ ] **Step 2: Run them to see them fail**

Run: `uv run pytest tests/test_taper.py tests/test_layout.py tests/test_params.py tests/test_measurements.py -q`
Expected: collection errors (`No module named 'dock.taper'`) and `test_design_rules_match_spec` failing on `THIN_WALL`.

- [ ] **Step 3: Write `src/dock/params.py`**

Replace the whole file with (the `V1_*` block is temporary):

```python
"""Design rules for the tapered dock. Millimetres. Change here, never inline
in a part module."""
from dataclasses import dataclass

WALL = 2.0         # base shell and tray dividers: 5 lines at 0.4 mm (v1: 2.4)
THIN_WALL = 1.6    # 2 perimeters a side: the tray's hidden outer walls, the lid's walls
FLOOR = 1.2        # base floor: 6 layers at 0.2 mm (v1: 1.6)
CHAMFER = 1.0      # downward-facing edge chamfer
CLR_FIT = 0.15     # coupon 2026-09-20, PLA on U1: 0.10 tight, 0.15 slides
CLR_BAY = 8.0      # device to a vertical (internal) bay wall; room for the cable beside it
CLR_BAY_OUTER = 3.0  # device to a sloped (outer) bay wall at the floor; the lean opens it
                     # to ~13 mm by the rim
TRAY_PLATE = 1.2   # tray floor: 6 layers; cable cutouts pass through it (v1: 3.0)
LID_PLATE = 1.2    # lid top: 6 layers
BAY_DEPTH = 38.0   # bay wall height above the tray plate (v2.1: was 32); must clear the
                   # tallest device (ION 30.2) so the lid does not touch it
TAPER_DEG = 15.0   # every outer face leans this far off vertical, like the Trek CHRGtime
CORNER_R = 30.0    # base rim corner radius; the draft shrinks it to ~R8 at the foot
BAND_H = 8.0       # colour line: dark foot band below, light body above
BED_X = 250        # U1 usable X with margin
BED_Y = 250        # U1 usable Y with margin
THRU = 400.0       # cutter length; longer than any part in this design

# v1 values, kept only until the v1 modules that use them are replaced
# (Tasks 4-6).  Task 6 deletes these three lines.
V1_WALL = 2.4
V1_FLOOR = 1.6
V1_CORNER_R = 8.0
V1_TRAY_PLATE = 3.0
CLR_RAIL = 0.20    # one step above CLR_FIT so the divider drops in by hand

@dataclass(frozen=True)
class Plug:
    """Cable connector overmold envelope (the moulded body, not the metal tip)."""
    width: float
    height: float
    length: float   # overmold length along the cable axis

# Typical overmold sizes; refine from the actual cables when measured.  The
# tray's cable cutouts are one size for all of them (see tray.CUTOUT), so
# these are sanity limits, not cutter inputs.
USB_A_PLUG = Plug(width=15.0, height=8.0, length=20.0)
USB_C_PLUG = Plug(width=11.0, height=6.0, length=18.0)
MICRO_PLUG = Plug(width=10.5, height=6.5, length=17.0)
```

- [ ] **Step 4: Point the v1 modules and tests at the `V1_*` copies**

```bash
sed -i -E 's/\b(P|params)\.(WALL|FLOOR|CORNER_R|TRAY_PLATE)\b/\1.V1_\2/g' \
  src/dock/base.py src/dock/tray.py src/dock/lid.py src/dock/divider.py \
  tests/test_base.py tests/test_tray.py tests/test_lid.py tests/test_assembly.py tests/test_divider.py
```

Then check nothing else in those files reads the changed names: `grep -nE "\b(P|params)\.(WALL|FLOOR|CORNER_R|TRAY_PLATE)\b" src/dock/{base,tray,lid,divider}.py tests/test_{base,tray,lid,assembly,divider}.py` prints nothing.

- [ ] **Step 5: Add `corner_r` to the charger**

In `src/dock/measurements.py`, add the field as the last field of `Charger`, after `led_offset_from_ports`:

```python
    # Radius of the body's rounded vertical edges, seen from above: the
    # charger pocket's corners follow it.  See docs/measuring.md.
    corner_r: float = 6.0
```

and in the `CHARGER = Charger(...)` call replace `led_offset_from_ports=None)   # the A2154 has no LED` with:

```python
                  led_offset_from_ports=None,   # the A2154 has no LED
                  corner_r=6.0)                 # NOMINAL until measured
```

In `docs/measuring.md`, in the `CHARGER` section, add after the `led_offset_from_ports` bullet:

```markdown
- corner_r: the radius of the body's rounded vertical edges, seen from
  above.  Hold a square (or a card) against one corner, flat on both faces
  that meet there, and measure how far back along one face the curve starts
  -- that distance is the radius.  The base's charger pocket rounds its
  port-face corners to `corner_r + CLR_FIT` so they follow the body.  NOMINAL
  6.0 until measured.
```

- [ ] **Step 6: Write `src/dock/taper.py`**

```python
"""The draft every outer face of the dock shares, and the rounded outlines
it is built from.

The Trek CHRGtime's walls lean about 15 degrees off vertical (measured off
its manual's to-scale front view), and so do this dock's -- base, lid and
the tray inside, one continuous slope from the lid top to the foot.  It is a
true draft: an Outline carried down by d mm steps in d*TAN on every side and
its corner radius shrinks by the same, so everything derived from one
Outline stays concentric with it, corners included.  That is what keeps a
wall a constant thickness through its corners, and the gap between the tray
and the base uniform all the way round.
"""
import math
from dataclasses import dataclass

from build123d import Part, Plane, Pos, Rectangle, RectangleRounded, Sketch, Vector, fillet, loft

from dock import params as P

TAN = math.tan(math.radians(P.TAPER_DEG))
COS = math.cos(math.radians(P.TAPER_DEG))

def horiz(t: float) -> float:
    """Horizontal width of a wall `t` thick measured square to a drafted face."""
    return t / COS

def bed_chamfer_inset() -> float:
    """Extra inset at the bed that makes a drafted wall's foot chamfer 45
    degrees: the draft already steps the outline in CHAMFER*TAN over it."""
    return P.CHAMFER * (1 - TAN)

@dataclass(frozen=True)
class Outline:
    """A rounded rectangle centred on the Z axis: `sx` by `sy`, corner radius
    `r`, at height `z_ref`.  Carried up or down the draft it grows or shrinks
    by TAN per mm on every side, radius included."""
    sx: float
    sy: float
    r: float
    z_ref: float

    def at(self, z: float, inset: float = 0.0) -> tuple[float, float, float]:
        """(sx, sy, r) at height z, then moved `inset` further in (negative: out)."""
        i = inset + (self.z_ref - z) * TAN
        return self.sx - 2 * i, self.sy - 2 * i, self.r - i

    def section(self, z: float, inset: float = 0.0) -> Sketch:
        sx, sy, r = self.at(z, inset)
        if r <= 0:
            raise ValueError(f"corner radius {r:.2f} at z={z:.2f}: the draft ran it out")
        return Plane.XY.offset(z) * RectangleRounded(sx, sy, r)

    def solid(self, z0: float, z1: float, inset: float = 0.0) -> Part:
        """The drafted solid between z0 and z1, `inset` in from this outline."""
        return loft([self.section(z0, inset), self.section(z1, inset)])

_CORNERS = {"--": (0, 2), "+-": (1, 2), "++": (1, 3), "-+": (0, 3)}

def corner_rect(x0: float, x1: float, y0: float, y1: float,
                radii: dict[str, float], z: float) -> Sketch:
    """Rectangle x0..x1 by y0..y1 at height z, each corner rounded by its own
    radius.  Keys "--", "+-", "++", "-+" name a corner by the signs of its X
    and Y; a missing key or a radius of 0 leaves that corner square."""
    s = Pos((x0 + x1) / 2, (y0 + y1) / 2) * Rectangle(x1 - x0, y1 - y0)
    xy = (x0, x1, y0, y1)
    for key, r in radii.items():
        if r <= 0:
            continue
        ix, iy = _CORNERS[key]
        s = fillet(s.vertices().sort_by_distance(Vector(xy[ix], xy[iy], 0))[0], r)
    return Plane.XY.offset(z) * s
```

- [ ] **Step 7: Write `src/dock/layout.py`**

```python
"""Where everything goes, as numbers: the tray's four bays, the outlines of
the tray, the base rim and the lid lip, and the heights they stack to.  No
solids here -- tray.py, base.py, lid.py and hinge.py build from these, and
the tests read them to know where to probe.

Coordinates: X and Y are shared by every part and centred on the dock.  Z is
each part's own: the tray's starts at its plate underside, the base's (and
the closed lid's, which is modelled sitting on the base) at the bed.

The bays are sized at the tray floor, and everything grows from there: the
tray's outer walls lean out at the draft from the floor up to its rim, the
base rim wraps that with TRAY_GAP and a WALL, and the lid continues the
slope above the rim.  Bay sides on the tray's outer wall are "sloped": a
device needs only CLR_BAY_OUTER there at the floor, because the lean opens
the gap to about 13 mm by the rim, which is where a cable runs.  Sides on an
internal wall stand vertical and keep v1's CLR_BAY.
"""
from dataclasses import dataclass

from dock import measurements as m
from dock import params as P
from dock import taper

CABLE_ROOM = 6.0          # headroom over the charger, under the tray
CUTOUT = (28.0, 16.0)     # cable cutout: (along the bay, across it), as v1
CUTOUT_INSET = 3.5        # cutout to the bay's end, clear of the R3 floor fillet
CUTOUT_GAP = 6.0          # cutout to the device, as v1
# The Ion Pro RT charges through a socket on its underside, so its bay has
# cutouts spread along it instead of one at the end.
UNDERSIDE_PORT_CUTOUTS = {"ion": 3}
SPARE_L = 46.0            # the spare bay: no device chosen yet
INNER_FILLET_R = 6.0      # vertical inside corners of the bays
FLOOR_FILLET_R = 3.0      # where every bay wall meets the floor
# The tray's outer wall runs this far (horizontally) clear of the base's
# inner wall, more than a fit clearance, so the ledge sets the tray's height
# rather than the two tapers wedging together.
TRAY_GAP = P.CLR_FIT + 0.3
TRAY_SINK = 0.3           # tray rim below the base rim: the lid lands on the base
LID_SLOPE_H = 5.0         # the lid's lower band, continuing the base's slope
LIP_H = 3.0               # its flared top band
LID_H = LID_SLOPE_H + LIP_H
LIP_W_MAX = 2.0           # how far the lip stands proud of the slope, bed allowing
BED_MARGIN = 0.25         # the lid is the widest part; keep it this far inside the bed

@dataclass(frozen=True)
class Bay:
    """A bay's floor rectangle, tray coordinates, and which of its sides
    (-X, +X, -Y, +Y) lie on the tray's sloped outer wall."""
    name: str
    x0: float
    x1: float
    y0: float
    y1: float
    sloped: tuple[bool, bool, bool, bool]

    @property
    def cx(self) -> float:
        return (self.x0 + self.x1) / 2

    @property
    def cy(self) -> float:
        return (self.y0 + self.y1) / 2

# Left bay: the ROAM, long axis along Y, its cutout at the -Y end.  Right
# column, stacked -Y to +Y: spare, TRACKR, Ion, long axes along X, lying
# against the partition with their cutouts at the +X end.
_LEFT_W = m.ROAM.width + P.CLR_BAY_OUTER + P.CLR_BAY
_LEFT_L = CUTOUT_INSET + CUTOUT[0] + CUTOUT_GAP + m.ROAM.length + P.CLR_BAY_OUTER
_RIGHT_W = (max(d.length for d in (m.ION, m.TRACKR))
            + P.CLR_BAY + CUTOUT_GAP + CUTOUT[0] + CUTOUT_INSET)
_TRACKR_L = m.TRACKR.width + 2 * P.CLR_BAY
_ION_L = m.ION.width + P.CLR_BAY + P.CLR_BAY_OUTER
_RIGHT_L = SPARE_L + P.WALL + _TRACKR_L + P.WALL + _ION_L
BAY_L = max(_LEFT_L, _RIGHT_L)          # the shorter column is stretched to match
FLOOR_X = _LEFT_W + P.WALL + _RIGHT_W   # the bays and the partition, at the floor
FLOOR_Y = BAY_L

_X0, _Y0 = -FLOOR_X / 2, -FLOOR_Y / 2
_XR = _X0 + _LEFT_W + P.WALL
_Y_TRACKR = _Y0 + SPARE_L + P.WALL
_Y_ION = _Y_TRACKR + _TRACKR_L + P.WALL
BAYS: dict[str, Bay] = {
    "roam": Bay("roam", _X0, _X0 + _LEFT_W, _Y0, -_Y0, (True, False, True, True)),
    "spare": Bay("spare", _XR, -_X0, _Y0, _Y0 + SPARE_L, (False, True, True, False)),
    "trackr": Bay("trackr", _XR, -_X0, _Y_TRACKR, _Y_TRACKR + _TRACKR_L,
                  (False, True, False, False)),
    "ion": Bay("ion", _XR, -_X0, _Y_ION, -_Y0, (False, True, False, True)),
}

# --- heights ------------------------------------------------------------------
TRAY_H = P.TRAY_PLATE + P.BAY_DEPTH
BASE_H = P.FLOOR + m.CHARGER.height + CABLE_ROOM + TRAY_SINK + TRAY_H
TRAY_Z0 = BASE_H - TRAY_SINK - TRAY_H   # the tray's underside, base coordinates

# --- outlines -----------------------------------------------------------------
_TRAY_WALL_H = taper.horiz(P.THIN_WALL)
_BASE_WALL_H = taper.horiz(P.WALL)
_TRAY_GROW = _TRAY_WALL_H + P.BAY_DEPTH * taper.TAN      # floor -> tray rim
_RIM_GROW = TRAY_GAP + _BASE_WALL_H + TRAY_SINK * taper.TAN  # tray rim -> base rim
# The tray's outer face at its rim (tray coordinates), and the base's at its
# rim.  One corner centre serves both, so the gap is uniform through the
# corners; CORNER_R is the base rim's.
TRAY_OUTLINE = taper.Outline(FLOOR_X + 2 * _TRAY_GROW, FLOOR_Y + 2 * _TRAY_GROW,
                             P.CORNER_R - _RIM_GROW, z_ref=TRAY_H)
RIM = taper.Outline(TRAY_OUTLINE.sx + 2 * _RIM_GROW, TRAY_OUTLINE.sy + 2 * _RIM_GROW,
                    P.CORNER_R, z_ref=BASE_H)
# The lid is the widest part: the lip gives way to the bed if it has to.
_SLOPE_TOP = RIM.at(BASE_H + LID_SLOPE_H)
LIP_W = min(LIP_W_MAX,
            (P.BED_X - _SLOPE_TOP[0]) / 2 - BED_MARGIN,
            (P.BED_Y - _SLOPE_TOP[1]) / 2 - BED_MARGIN)
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

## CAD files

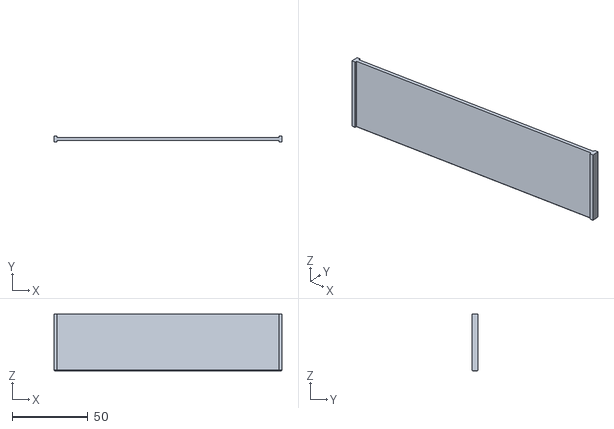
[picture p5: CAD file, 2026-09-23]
releases/v1-prototype/divider.stl
150.3 x 4.00 x 37.5

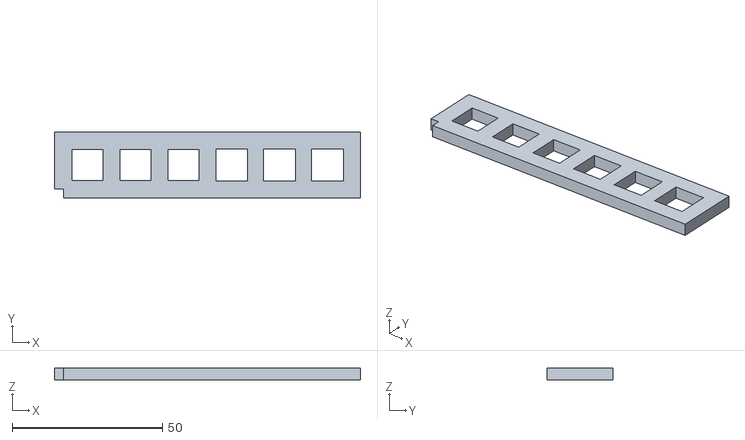
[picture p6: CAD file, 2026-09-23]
releases/v1-prototype/coupon_plate.stl
102.0 x 22.0 x 4.00

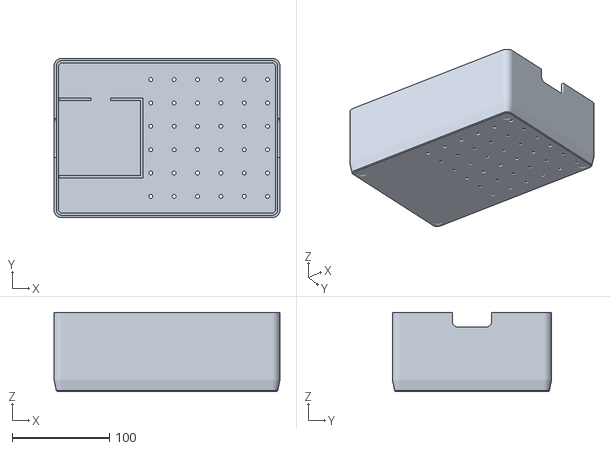
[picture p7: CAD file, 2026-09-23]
releases/v1-prototype/base.stl
232.2 x 163.7 x 81.6

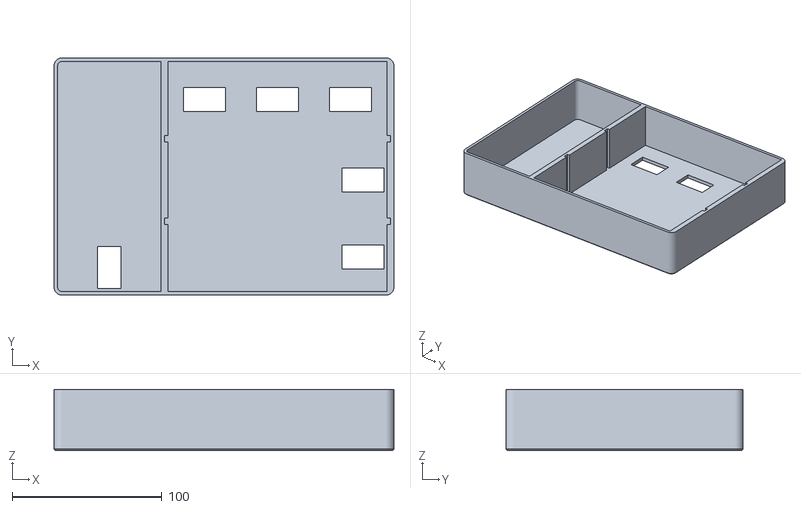
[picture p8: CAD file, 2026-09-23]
releases/v1-prototype/tray.stl
227.1 x 158.6 x 41.0

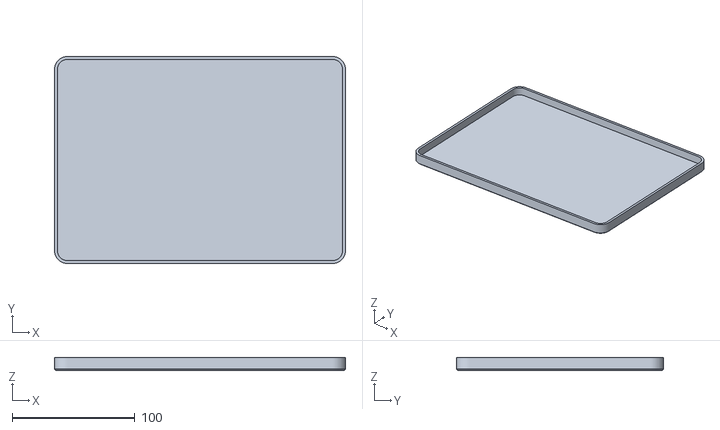
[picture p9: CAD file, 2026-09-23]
releases/v1-prototype/lid.stl
237.3 x 168.8 x 10.4

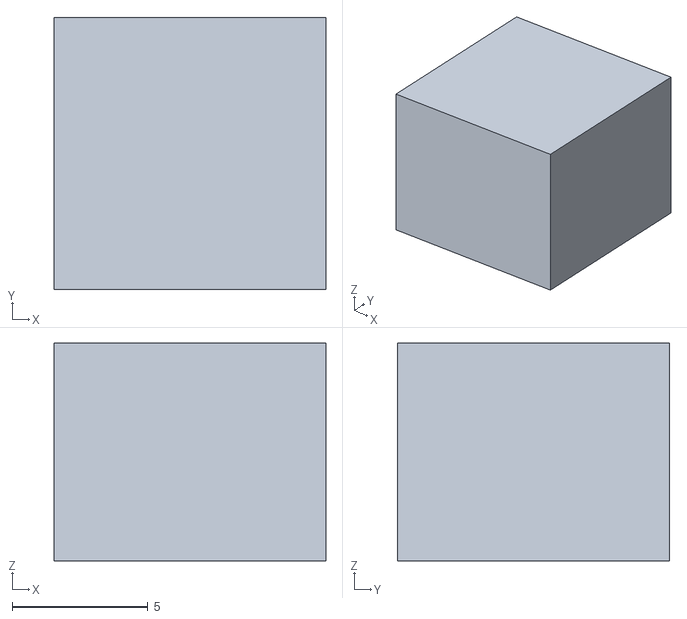
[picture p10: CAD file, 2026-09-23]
releases/v1-prototype/coupon_peg.stl
10.0 x 10.0 x 8.00

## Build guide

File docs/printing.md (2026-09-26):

# Printing on the Snapmaker U1

Slicer: Snapmaker Orca (open the .stl files; Orca rejects generic 3MF), installed as a Flatpak.

    flatpak run io.github.Snapmaker.Snapmaker_Orca

Printer: Snapmaker U1. Material: PETG for the final set (fit-checking in PLA
is fine). Profile: 0.4 mm nozzle, 0.2 mm layers; 0.28 mm Extra Draft is an
option for the base and lid, see below.

| Part | Orientation | Walls | Infill | Supports |
|---|---|---|---|---|
| fit_test_plate, fit_test_peg | as exported | 3 | 15 % | none |
| hinge_test_base | as exported | 3 | 15 % | none |
| hinge_test_lid | as exported: leaf up | 3 | 15 % | under the pins if needed |
| tray | as exported: plate on the bed, bays up | 3 | 15 % | none |
| base | as exported: open top up | 3 | 15 % | none |
| lid | as exported: top face down, hinge leaves up | 3 | 15 % | under the leaf pins if needed (paint-on) |

There are no dividers to print: the tray's dividers are fixed and print with it.

## Efficiency

`uv run python scripts/slice_report.py` slices the exported base, tray and
lid headlessly with these settings and prints time and grams next to the v1
prototype (`--layer 0.28` for the draft profile). Last measured
2026-09-24 (concealed leaf hinge), 0.20 mm PETG: v1 set 14 h 00 m / 582 g,
this set 9 h 38 m / 411 g (time -31 %, filament -29 %). Re-run it after any
change to params.py and before a reprint.

`uv run python scripts/orca_project.py` builds `out/orca/dock_plates.3mf`,
one Orca project with each part on its own named plate (Base, Tray, Lid,
Hinge test, Fit test) on the same U1 / 0.20 / PETG profiles. Run
it after `export_all.py` (and `slice_report.py` once, which writes the
profiles it loads), then open the project in Orca. Supports, the base's
colour change and the prime tower are set in the GUI.

The base and lid can also print at 0.28 mm Extra Draft for a little more
time saved; the tray's cable cutouts and fillets look better at 0.20.

## Two-tone base

The base is two colours like the Trek CHRGtime: a dark foot band and a light
body. The colour line is the V groove round the foot at `BAND_H` (8 mm);
it is 1.2 mm tall, so any layer inside it works at 0.20 or 0.28:

1. In Orca, load the dark filament in one toolhead and the light in another,
   and set the base's object filament to the dark one.
2. Add a filament change to the light filament at the first layer above
   8.0 mm -- 8.2 mm at 0.20 -- on the layer slider ("+" or right-click,
   "Change filament"). 8.0 mm is also the charger fence's top, so the whole
   fence prints dark, and 8.2 is still inside the groove.
3. Turn the prime/wipe tower off for this plate (Others > Prime tower): one
   change on a toolchanger does not need it, and the tower would cost more
   than the whole change.

Print the lid and the tray in the dark colour.

## Geometry notes

Every outer face leans 15 degrees (the CHRGtime's angle), from the lid top
down to the foot; the corners run from R30 at the rim to about R8 at the
bed. The base walls lean outward as they rise, well inside 45 degrees, so
the base prints without supports -- turn them off for it, or Orca's
automatic ones will fill the ports. Every cable hole -- the AC cord port,
the two escape ports and the tray's cutouts -- is an oval, so the ports'
flat heads (10 mm at most) and the foot recesses are short bridges, and the
hinge's socket blocks inside the back wall sit on 45-degree chins.

The charger (Anker A2154) stands in a U fence backed onto the -X end wall;
its arms run into the leaning end wall and fuse with it, its top is the
colour line, and the pocket floor is filleted along its two side walls to
follow the charger's rounded bottom edges (`CHARGER.edge_r`). The
mains cord plugs in from outside through the cord port, sized for a
figure-8 (C7) end; if your cord's moulding is square-cornered, measure it
(docs/measuring.md) before printing the base. Two oval escape
ports, one each side of the charger in the same wall, let a cable out to
charge something outside the dock.

The tray rests on a ledge ring 0.3 mm below the rim, so the lid lands on the
base. Lift it out by its walls. The cable
cutouts at the bays' outer ends drop past the leaning base wall: the cable
falls clear for at least 15 mm, then follows the wall down.

## Hinge

A concealed leaf hinge, after the Trek CHRGtime's, at two stations on the
+Y long side. At each, a leaf on the lid hangs into a notch in the base's
back wall, flush with it, and Ø6 pins on the leaf's ends sit in sockets in
blocks on the inside of the wall. From behind, a closed dock shows only the
two leaves in their notches and a 1.5 mm gap along the back seam (the
lid's back is raised off the rim so it can turn about a pivot inside the
wall line).

To fit the lid: set it closed on the rim with the leaves over their notches
and press the back edge down until the pins snap into their sockets; to
take it off, lift the back edge straight up. The snap is deliberately
light. Opened fully it stops at about 101 degrees, the leaves' ends resting
on small lips on the socket blocks.

Print the hinge test first: it is one station cut from the real base and
lid. If the pins will not snap in, or pop out, change `SNAP` in
`src/dock/hinge.py`; if the hinge binds, raise `BORE_CLR`; check it stops
at about 100 degrees and the lips hold. Then re-export.

## Print order and measurement cycle

1. **test prints** -- the fit test and the hinge test, in the final
   material. Set `CLR_FIT` (params.py) and `SNAP` / `BORE_CLR` (hinge.py).
2. **measurements** -- fill in `src/dock/measurements.py` per
   `docs/measuring.md`; `CHARGER.edge_r` is new.
3. **tray** -- check each device seats in its bay and its cable plugs in
   cleanly through the cutout.
4. **base** -- check the charger drops into the fence and the tray seats on
   the ledge.
5. **lid** -- check it snaps into its sockets, stays on resting fully open,
   swings shut flush with the
   rim, and clears every device.

Re-run `uv run python scripts/export_all.py` after any parameter change, and
`uv run pytest` before reprinting.

## Flatpak note

The Snapmaker Orca Flatpak has no host filesystem access by default, so
`flatpak run ... out/part.stl` opens the app but reports "no geometry data".
Either grant it this folder once:

    flatpak override --user --filesystem=$PWD io.github.Snapmaker.Snapmaker_Orca

or launch it without arguments and use File > Import (the file portal).

The GUI also changes its working directory after launch, so pass ABSOLUTE
paths on the command line (`$PWD/out/part.stl`); relative paths fail with
"no geometry data".

To verify every part loads in Orca without opening the GUI:

    scripts/orca_check.sh

It writes Orca project files to out/orca/<part>.3mf, which File > Open
Project in Orca accepts directly.

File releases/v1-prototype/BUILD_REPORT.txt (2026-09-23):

build report (mm)
  base    232.20 x  163.70 x  81.60
  tray    227.10 x  158.60 x  41.00
  lid     237.30 x  168.80 x  10.40
  cavity room past the fence: X 135.90 in front, Y 36.00 per side
  charger backed against the -X wall; port room 138.30 (need 40.00)

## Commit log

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2026-09-19 Add clearance calibration coupon
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2026-09-19 Fix cradle review findings: tilt test, chamfers, slot inset, dead code
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2026-09-19 Plan: rail cutter clearance rationale and deck placement
2026-09-19 Fix divider review findings: clarify rail_cutter clearance rationale
    Add X-dimension assertion to test_cutter_is_larger_than_rail_by_clearance
    and docstring explaining why X gets single clearance (bearing face) while
    Y gets 2x clearance (sideways pull-out tolerance).
2026-09-19 Add deck with cradles, spare bay, lip and plug wells
    The deck carries the three cradles and a spare bay in one row, a lip
    skirt that drops into the base, and a WALL-thick plug well under each
    floor slot so the device-end plug is held captive over its full
    overmold length. Wells are deeper than the lip, so they set the part's
    Z offset; WELL_H is exported for the base cavity.
2026-09-19 Add base tray with rebate, charger fence, cord notch, escape port
    Open-top box from x=0 to BASE_X, centred in Y, matching the deck's
    convention. Walls below the rebate are 2*WALL thick so the top rebate
    (DECK + 2*CLR_FIT) leaves a 2.4 mm shelf; the 198.2 mm plate lands on
    2.2 mm of it. Rear-wall cutters are 6*WALL deep and centred on the
    outer face so each passes fully through the 2*WALL wall (the brief's
    3*WALL cutter stopped 1.2 mm short). The cord notch is held clear of
    the -X wall so the rear-left corner keeps its full section.
2026-09-19 Fix base tray review findings: inlet room, seat transform, solid-measured tests
    - INLET_PLUG_ROOM = 25.0 moves the fence so the C7 cord can reach the
    charger inlet; the cord notch follows the fence.
    - deck_seat() exports the rebate seating transform; docstring no longer
    claims the deck and base share an origin.
    - Fence-fit and inlet-room tests now measure the solid (horizontal
    cross-sections) instead of restating the constants; the
    CH_W + 2*WALL < CAVITY_Y tripwire is kept.
    - FOOT_RECESS_D = 0.6 leaves 1.0 mm of floor.
    - CABLE_ROOM = 20.0 per controller ruling; BASE_H 47.6 -> 55.6.
    - Escape port dropped one wall so the rebate ledge is continuous.
    - Rear cutters span the wall plus 0.2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
2026-09-19 Add assembly fit tests and printing guide
    Adds tests/test_assembly.py covering plate/rebate clearance, seated
    non-intersection, plate-flush arithmetic and a solid-measured flush
    check, and bed footprint. Moves the rear-wall AC cord notch to centre
    on the free space behind the C7 plug (CAVITY_MIN_X + INLET_PLUG_ROOM/2)
    instead of the inlet face, per the Task 7 review. Adds docs/printing.md
    and a README Workflow section.
2026-09-19 Fix assembly test review findings round 1
    Remove test_assembled_parts_do_not_intersect (duplicate of
    test_deck_seats_in_the_rebate_without_interference in test_base.py).
    Rewrite test_plate_fits_rebate_with_clearance and
    test_assembled_footprint_within_bed to measure the built solids
    instead of comparing constants. Drop the pure-arithmetic
    test_plate_top_is_flush_with_base_top now that the solid-measured
    flush test covers it. Note in the cord-notch comment that the max()
    clamp is inert under current constants.
2026-09-19 Fix charger orientation: ports on the long face, along Y
    The PowerPort 6's six USB-A ports are on its 96 mm face and the C7 inlet on
    the opposite 96 mm face, so `Charger.length`/`width` were physically swapped.
    Rename them `port_face_width`/`port_to_inlet` and lay the charger flat with
    the port face running along Y: pocket X = port_to_inlet + 2*CLR_FIT, pocket
    Y = port_face_width + 2*CLR_FIT, ports toward +X, inlet toward -X.
    Consequences:
    * the AC cord notch moves to the -X end wall, the LED window to the +X end
    wall (centred on the charger's mid-height, not MIN-aligned); the device
    cable escape port stays in the rear (-Y) wall,
    * INLET_PLUG_ROOM goes 25 -> 45 mm, leaving 83.4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
2026-09-19 Export the divider at the size the spare bay actually wants
    `build_divider(40, 50)` passed height and width the wrong way round and both
    were guesses. Make the signature keyword-only so that cannot recur, and
    export height=SPARE_H, width=SPARE_W - CLR_RAIL so the slab clears the bay
    walls while the rails still reach into the slots.
    Expose deck.RAIL_YS / deck.RAIL_X (the bay already computed both inline) and
    assert on the solids that the divider seats in either rail position without
    touching the deck, and that its rails do reach past the bay wall.
2026-09-19 Take the Roam's USB-C in through the pocket wall, not the floor
    Wahoo puts the Roam 3's USB-C on the bottom edge, so boring the shelf floor
    under the device was wrong. Add `Slab.port_face` ("bottom"/"back") and, for
    a bottom port, leave the floor solid and bring the plug in horizontally:
    * a plug-sized channel pierces the pocket's low (-Y) wall at floor level
    (its only ceiling is the 2.4 mm wall -- a short bridge),
    * an open trough of the same cross-section, USB_C_PLUG.length + 2 long,
    runs on in a nose ahead of that wall,
    * a cable slot at the trough's far end drops to the bed face.
    The nose lengthens the wedge run, so the tilt lift is now derived from the
    whole solid's -Y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
2026-09-19 Tidy-ups: shared plug cutter, whole-part tests, overhang allowlists
    * params.plug_cutter() and params.THRU replace the three near-identical
    plug-slot boxes and the two different _THRU lengths in cradles/deck.
    * delete the empty tests/conftest.py; drop the unused `import math` from
    deck.py and `GeomType` from cradles.py.
    * tests/test_parts.py: every part in export_all.PARTS is one valid solid
    with its bed face on Z=0 (export_all already guards its main block).
    * test_coupon asserts both coupon parts are valid single solids.
    * test_assembly._rebate_opening_size aggregates min/max across all ledge
    faces, as test_base already did -- the end-wall cut-outs split the ledge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
2026-09-19 Self-review polish: docstrings and dead aliases
    Drop the _CTR_MINZ alias (it was _MIN under another name) and the now-unused
    ROAM_CABLE_W, name the cable slot's set-back, and bring the cradles and deck
    module docstrings in line with the bottom-port Roam, whose plate bore passes
    the cable rather than gripping a plug.
2026-09-19 Put the Roam plug channel level with the USB-C port
    The Roam lies back-down on the pocket floor, so its bottom-edge port sits
    at its own mid-thickness above that floor, not on it. The channel and
    trough were cut from the pocket floor upward and missed the port by ~5 mm.
    Slab gains an optional port_height (centre of the charge port above the
    face the device rests on; None means thickness/2), and the channel, the
    trough and the nose that carries it are now centred on that height. The
    cable slot follows the trough floor, clamped clear of the wedge's
    chamfered front edge -- raising the trough tilts that landing point
    further toward -Y.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
2026-09-19 Put the charger where the LED window can see it, and fix the LED side
    Two related base fixes.
    The fence was anchored to the -X (inlet) end of the cavity, which left the
    charger 83 mm from the +X end wall that carries the LED window -- an LED
    shining down that much air lights the cavity, not the window. The fence is
    now placed from the +X side at PORT_PLUG_ROOM_MIN (40 mm), which puts the
    window a fixed 2*WALL + 40 = 44.8 mm from the port face. The slack lands
    on the inlet side (88.4 mm, against a 45 mm floor), where the C7 cord just
    lies along the cavity floor to the inlet; the cord notch is unchanged.
    LED_Y assumed the LED sat inboard of port 1 and so landed on port 2. The
    PowerPort 6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
2026-09-19 Export STL and STEP only; Snapmaker Orca rejects the generic 3MF
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2026-09-20 Add flat tray with four bays, cable cutouts and divider rails
    Tray is 201.1 x 132.6 x 31.0: one ROAM bay on the left, three bays
    stacked in Y on the right, each with a 22 x 12 cable cutout through the
    plate at its outer end. The partition and +X outer wall are thickened to
    WALL + RAIL_D + CLR_RAIL so the two removable-divider rail slots leave a
    full 2.4 mm behind them. Outer vertical corners R5.45, plate bottom edge
    chamfered 1.0; prints plate-down with no overhang.
    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
2026-09-20 Raise BAY_DEPTH to 32 and pin the tray's layout with positional tests
    Controller ruling: 28 mm walls did not clear the ION (30.2) or TRACKR
    (29.1), so the lid would have touched a device. BAY_DEPTH is now 32.0 and
    a test asserts it stays at least 1 mm above the tallest device. TRAY_H
    follows to 35.0; every other tray dimension is unchanged.
    The tray tests asserted sizes but no positions, so a mirrored or
    misplaced layout would have passed. Added tests that read the cutout
    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
2026-09-20 Rebuild base for the tray: rounded corners, rebate, tie-down grid
    The base is 206.2 x 137.7 x 77.6: outer corners R8, a 2*WALL shell below
    the rebate with its cavity corners cut concentric at R3.2, and a 35 mm
    rebate sized to the tray plus CLR_FIT that leaves a 2.4 mm ledge (2.25 mm
    of bearing once the tray's fit clearance is taken).
    The charger fence keeps 40 mm of plug room in front of the ports and
    leaves 91.3 mm behind the inlet and 13.5 mm of Y clearance per side, so
    BASE_Y does not have to grow. Cord notch, LED window and escape port are
    cut only through their own wall; the escape port lands under the tray's
    spare bay. 28 tie-down holes on a 12 mm pitch fill the floor between the
    fenc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
2026-09-20 Base review fixes: closed cord port, real ledge probes, bottom chamfer
    Review round 1.
    The -X cord notch becomes a closed 20 x 16 port with its sill 2 mm above
    the cavity floor, so the rim and the rebate shelf are continuous rings
    again; its 20 mm ceiling is an allowed bridge.
    The ledge test was vacuous - it measured the bbox of an annular face set,
    which is the rebate opening, not the shelf. It now probes a band offset
    from the cavity outline (corners included, since offsetting a rounded
    rectangle keeps the arc centres) and asserts it is solid below the shelf
    and void above it. BEARING_W drops from 2.25 to 1.25: the tray's 1.0 mm
    bottom chamfer eats that much of the shelf, and a new test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
2026-09-20 Add lift-off lid
    A WALL-thick top plate with an 8 mm skirt that drops over the outside of
    the base, CLR_FIT clear per side. All three corner radii are concentric
    with the base's R8, so the gap is uniform through the corners.
    Built in print orientation, plate face on the bed: the only downward
    faces are the bed face and its 45 degree chamfer, so it prints with no
    bridge and no overhang. `lid_seat()` flips it onto the base for fit
    checks -- plate underside on the rim at BASE_H, skirt hanging 8 mm down.
2026-09-20 Assembly tests and v2 printing guide
    Add cross-part fit checks (lid vs seated tray, devices vs seated lid,
    dividers vs base/lid, assembled footprint vs bed) not already covered by
    the per-part test suites, and rewrite the printing guide, README and
    CLAUDE.md to describe the v2 tray/base/lid/divider parts instead of the
    old cradle/deck design.
2026-09-20 Size the cord port from the moulded C7 cord end
    The AC cord port was a round-number 20 x 16 rectangle with a 20 mm bridge
    for a ceiling. Size it from the thing that has to pass it instead:
    measurements.CORD_END (NOMINAL C7, 24 x 14 x 30) plus 1 mm of slack per
    side, giving CORD_W 26 and CORD_H 16.
    26 mm is past the bridge allowance, so the port is no longer a rectangle:
    a 45 degree peak CORD_W / 2 tall sits on the opening, so the ceiling is two
    self-supporting planes meeting at a ridge and the overhang test still has
    nothing to allowlist. The port still ends well below the rebate ledge.
    Tests measure the new shape on the solid: a CORD_END-sized block slides
    through the wall untouched, th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
2026-09-20 Round the ROAM bay's -X corners so the shell keeps WALL there
    The tray's outer vertical corners are rounded to OUTER_R (5.45) but the bay
    voids behind them were square, so on the diagonal -- the shortest line from
    the outside world to the void -- the -X corners were only 1.1 mm of shell,
    less than half a wall.
    Fillet the ROAM bay void's two -X vertical corners to OUTER_R - WALL (3.05)
    before cutting. That arc is concentric with the outer corner, so the wall
    there is exactly WALL all the way round the corner. The right column's +X
    corners stand behind the thicker RAIL_WALL and already measure 4.2 mm on the
    same diagonal, so they are left square.
    New test probes all four corners along thei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
2026-09-20 Cut a finger notch in each end rim to lift the tray out
    The tray seats flush with the base's rim, which left nothing to grip: the
    only way out was to turn the whole dock over. Each end rim now carries a
    notch NOTCH_W (40) wide, centred on Y = 0 and NOTCH_D (15) down from the
    rim, with its bottom corners rounded NOTCH_R (5) so the WALL-thick rim does
    not end in a sharp inside corner.
    The notch floor faces up and the rounded corners are convex in the
    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
2026-09-20 Leave the divider half a millimetre under the lid
    The divider was exported at exactly BAY_DEPTH, so its top finished level
    with the tray rim -- the same plane the lid ceiling lands on. A loose part
    that drops into its rails by hand and touches the lid is what makes a lid
    rock, and a squashed first layer would have held it proud on its own.
    Export it at BAY_DEPTH - 0.5, and chamfer its bed edge: build_divider takes
    a bottom_chamfer (0.5 by default), which follows the downward-edge rule for
    a part that prints standing on that edge and doubles as elephant-foot
    relief so it seats the whole way down its slots.
    Tests measure the gap, not the absence of an overlap: the seated divider --
    built th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
2026-09-20 Widen the LED window to 8 x 4
    The window was a 4 mm square aimed at an LED whose position along the port
    face is the least certain number on the charger (led_offset_from_ports is
    NOMINAL). Widen it to LED_W 8 in Y, where a miss means seeing nothing, and
    keep LED_H at 4 in Z, where the size is what has to bridge.
    The overhang test's docstring catches up with the cord port's peaked roof
    while it is here: the port no longer bridges at all, and the notch floors
    face up, so the bridges left are the escape port, this window and the foot
    recesses.
2026-09-20 Drop the v1 leftovers from params
    plug_cutter and USB_C_CABLE were written for the v1 cradle dock and nothing
    in the tray dock calls them: every bay gets the same 22 x 12 cable cutout
    through the plate, and there is no cradle with a cable slot any more. With
    plug_cutter gone params imports no geometry at all, which is what a module
    of design rules should look like.
    The remaining Plug entries stay as the sanity limits on that one cutout,
    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
2026-09-20 Print a build report after exporting
    The derived sizes and the leftover room round the charger were constants
    with no consumer: FENCE_MARGIN_X/Y, PORT_PLUG_ROOM and INLET_ROOM were
    computed and never read, and the part sizes were only ever seen by the
    tests. Every one of them moves on its own when a measurement or a design
    rule changes, and by then a print is already running.
    export_all now prints them after the files it wrote, each clearance beside
    the minimum it has to beat.
2026-09-20 Tidy the tray module and its tests
    _MIN_XY aligns all three axes to MIN, not two: _MIN_XYZ. The Ion bay gains
    the note that explains why its cutout is a through-hole -- the micro-USB
    overmold is taller than the plate, so it hangs in the cutout rather than
    standing on it. And the device-fit test's one-element loop, which unpacked
    two variables it never used, is written out as what it always was.
2026-09-20 Polish after reading the whole diff back
    No behaviour change: a missing blank line before build_report, a hardcoded
    26 mm in the cord cutter's docstring that would go stale the moment
    CORD_END is remeasured, a corner table in the tray tests that encoded -X as
    the truthiness of 180, an unused unpack and a stray quote style.
2026-09-21 v2.1: roomier bays after the first tray print
    CLR_BAY 3 -> 8, cutouts 22x12 -> 28x16, BAY_DEPTH 32 -> 38, spare bay
    40 -> 46. Tray 227 x 159 x 41, base 232 x 164 x 84, lid 237 x 169;
    all still inside the 250 mm bed.
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2026-09-21 Stand the cable loops off past the plugs, not just past the fence
    LOOP_STANDOFF was 6 mm, which put the loop row at X 194.3-197.3 -- inside
    the space the six USB-A overmolds occupy in front of the charger's port face
    (187.4-207.4). Every cable would have had to be plugged in through a loop,
    which is to say none of them could. It is now 24 mm, the overmold plus room
    for the cable to turn down out of the plug -- so the row stands at
    212.3-215.3, 4.9 mm past the plugs and 12.1 mm short of the +X cavity wall.
    That leaves no room for a pitched tie column beyond the row, so the tie grid
    goes back to spanning the whole free floor and drops the points that would
    foul a loop instead, exactly as it a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
2026-09-21 Swap the charger for the Anker A2154, and let the ports drive the geometry
    The dock was built round an Anker PowerPort 6 (A2123). It is now built round
    the A2154: 77 x 82 x 33 mm, six ports in one row, AC inlet centred on the
    back, no status LED. The base grows 7 mm taller to 232.2 x 163.7 x 90.6 --
    X and Y are tray-driven and did not move -- the fence gets 36 mm of Y
    clearance a side instead of 26.5, and the extra 17 mm of charger depth comes
    out of the inlet room, which still has 100.3 against a needed 45.
    Two things stop being hard-coded. Charger.port_pitch is a measurement now,
    so base.PORT_PITCH is no longer a 15.2 literal and the cable loops land on
    the real port centres; and led_offs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
2026-09-21 Put the cord port on the inlet, and clear the stale numbers out of the comments
    The cord port sill was a flat FLOOR + 2, which on the A2154 left the inlet
    1.5 mm below the shoulder where the 45 degree roof starts -- the cord end
    would have gone in tilted up toward the ridge. It is derived now:
    CORD_Z0 centres the rectangular opening on the inlet, clamped at
    CORD_Z0_MIN so a low inlet cannot drive the sill onto the cavity floor. The
    opening runs 10.1 to 26.1 with the inlet at 18.1, 8 mm of clearance either
    way. Everything above it rises with it: the roof apex to 39.1 and the escape
    port to 40.1-48.1, which leaves 1.5 mm of wall under the rebate ledge --
    tighter than the 8 mm it had, still ove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
2026-09-21 Back the charger onto the -X end wall, the way the CHRGtime stands it
    The manual shows the supply with its back to the end wall: the AC cord
    plugs in from outside, through the wall, straight into the inlet, and the
    ports face the middle of the cavity with the cables running under the bar
    toward it. Our pocket sat mid-cavity instead, with INLET_PLUG_ROOM asking
    for 45 mm of cord room behind the inlet and actually leaving 100.
    So the pocket now starts a fit clearance off the cavity wall, that wall is
    the charger back stop, and the fence loses its -X wall: it is a U of two
    side walls and a front wall, standing CLR_FIT clear of the cavity wall so
    it prints as its own island. INLET_PLUG_ROOM i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
2026-09-22 Flatten the AC cord port's roof: rectangle, printed with supports
    The 45 degree peak dodged a 26 mm bridge the printer could not cross
    unsupported, but the user is happy to print the base with supports, so
    the port is now a plain CORD_W x CORD_H rectangle and its flat ceiling
    becomes the one ceiling in the part (SUPPORTED_CEILINGS) that needs
    print supports. Dropped CORD_PEAK; CORD_TOP now equals CORD_H. The
    escape port above it drops with the lower roof (ESCAPE_Z0 = CORD_Z0 +
    CORD_H + 1.0), gaining margin below the rebate ledge.
    tests/test_base.py: replaced the self-supporting-peak test with one
    that measures the flat rectangular opening and its bridging ceiling,
    and re-checks the moulded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
2026-09-22 Remove the cable-loop comb: the A2154's own cable block replaces it
    The Anker A2154 ships with a silicone cable-management block, so the
    printed under-tray loop row is unnecessary. Delete _loop_row, the LOOP_*
    constants and the loop-aware tie-hole keep-out; the tie-down grid now
    covers the full floor from the fence to the +X cavity wall. Keep the
    six port centres (renamed PORT_YS) for the plug-clearance test, and
    update docs/printing.md and test docstrings to describe cables running
    across the open floor to their tray cutouts.
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2026-09-23 Snapshot the v1 prototype STLs
    [base.stl, coupon_peg.stl, coupon_plate.stl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]
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2026-09-24 Assembly tests: tray seat, lid swing and stop, hinge snap, cable drop
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2026-09-24 Minor review cleanups: rounding, a bisection guard, stale wording
    Final-review findings 3-9 (docs/superpowers/sdd/2026-09-24-tapered-dock/),
    batched:
    - slice_report.py _fmt: round the total minutes before splitting into
    h/m, so it can never print "Xh60".
    - hinge._heel_closed_deg: assert the bisection bracket actually brackets
    the root before bisecting, with a clear message.
    - Drop the unused `taper` import in test_assembly.py and the unused
    `below` local in test_base.py.
    - Reword the "3 mm bridge" wording in hinge.py's docstring and
    docs/printing.md: the pin's flat is 3 mm wide, but the bridge it forms
    spans ~8.6 mm between the cheeks.
    - Fix stale comments: params.py pointed at th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
2026-09-24 Oval cable holes everywhere; 3x wider hinge with downward mouths and a light snap
    All cable holes are now stadium ovals: the tray's six cutouts and the AC
    cord port join the escape ports. The cord port's flat top now bridges, so
    the base prints with no supports; the hinge pins' flats are the one long
    bridge (base.LONG_BRIDGES).
    Hinge: hooks, cheeks and heel 3x wider (24 / 12 / 24 mm), round bores,
    mouths straight down with the lid closed (press on, lift off), snap 0.2,
    bore clearance 0.4, open angle 100 deg so the resting lid does not push
    its hooks off the pins. Lid bores print on supports.
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2026-09-24 Tray: drop the finger slot and the headlight bay's extra cable holes
    The tray lifts out by its walls, so the partition is solid again. The Ion
    is being replaced by a light that charges from its back, so its bay keeps
    the Ion's size but gets one cutout at its outer end like the others.
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2026-09-24 Hinge: a concealed leaf hinge after the Trek CHRGtime's
    Each station is now a leaf on the lid hanging flush into a notch in the
    base's back wall, with heavy-duty 6 mm pins on its ends snapping down into
    sockets in blocks inside the wall. Small lips on the blocks stop the lid at
    about 101 deg without blocking the press-on/lift-off path (leaf 8.5 mm below
    the pivot so they can). The lid's back is raised 1.5 mm off the rim so it
    can turn about a pivot inside the wall line. The tray's back wall steps in
    round each hinge, and the headlight moves 3 mm forward in its bay to clear
    the right-hand step. Socket blocks and lip risers have flat undersides and
    print on supports. The hinge coupon is now cu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
